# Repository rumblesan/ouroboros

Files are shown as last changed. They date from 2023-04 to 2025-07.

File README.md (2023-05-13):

# Ouroboros

A noisy feedback system

## Description

A pinged filter feeds a PT delay, which feeds a comparator, which feeds some clock dividers, which pings the filter and modulate the rest of the system

## Contact

Drop me an email at guy@rumblesan.com

## License

Creative Commons Licence
This work is licensed under a [Creative Commons Attribution 4.0 International License]("http://creativecommons.org/licenses/by/4.0/")

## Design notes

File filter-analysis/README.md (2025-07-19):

# Filter design docs

For rev 1 and 2 the filter used LM13700 OTAs for the filter.
Rev 3 has been redesigned to use the 2164 gain cell.

This folder has the analysis of the first versions of the filter, but the analysis for the 2164 version still needs to be added.

## Creating

`pdflatex lm13700-filter.tex`

## Contact

Drop me an email at guy@rumblesan.com

## License

Creative Commons Licence
This work is licensed under a [Creative Commons Attribution 4.0 International License]("http://creativecommons.org/licenses/by/4.0/")

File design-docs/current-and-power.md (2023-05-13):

# Current and Power Calculations

## 5V Supply

The 5V rail supplies :

* PT2399 IC
    draws up to ~30ma, less at lower speeds
* CD4020 IC
    Draws up to ~5ua (negligable)
    Output goes straight into a high input impedance buffer so minimal draw there as well.
* ATTiny85
    draws ~2ma (need to properly calculate but it's in this region)
* The 100k Division control potentiometer
    negligable

### Power

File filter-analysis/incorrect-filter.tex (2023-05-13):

\documentclass{article}

\usepackage{amsmath}
\usepackage{graphicx}
\usepackage{enumitem}

\title{Incorrect Filter}
\author{Guy John \\ \texttt{guy@rumblesan.com}}

\begin{document}

\maketitle

\section{Introduction}
Analysis of the original, incorrect design of the Ouroboros filter. Heavily based on the Serge VCFQ, but also with influence from the Mutable Instruments Blades. Much of this is pulled verbatim from the SSM2164 SVF Analysis by Emilie Gillet and then just somewhat modified.

\newpage

\subsection{Notations}

\begin{description}
\item $R_i$ is the value of the resistor through which the input signal is fed to the circuit.
\item $R_f$ is the value of the resistor through which the output signal of the integrator is fed back to the input.
\item $R_s$ is the value of the resistor from the OTA inputs to ground.
\item $C$ is the value of the integrators' capacitors.
\item $R_g$ is the value of the resistor through which the HP and LP outputs are fed back into the input.
\item $R_q$ is the value of the resistor through which the attenuated BP output is fed back into the input.
\item $v_{cv}$ is the cutoff frequency control voltage.
\item $v_q$ is the resonance control voltage.
\item $v_i(s)$ is the input voltage.
\item $v_{hp}(s)$, $v_{bp}(s)$ and $v_{lp}(s)$ are the high-pass, band-pass and low-pass output voltages.
\end{description}

\subsection{OTA Integrator Cell}

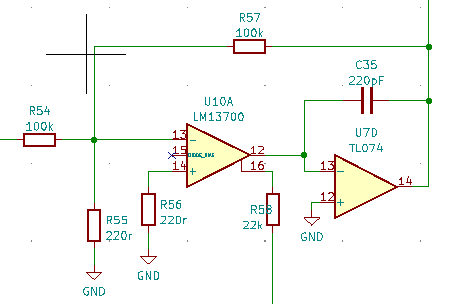
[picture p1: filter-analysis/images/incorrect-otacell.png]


The transfer function of an OTA is:

\begin{equation*}
\begin{split}
  i_o & = g_m(v_+ - v_-) \\
  i_o & = 19.2i_{cv}(v_+ - v_-) \\
\end{split}
\end{equation*}

If $R_f$ is equal to $R_i$
Kirchoff in $v_-$ gives:

\begin{equation*}
\begin{split}
  \frac{1}{R_i}(v_i(s) - v_-(s)) + \frac{1}{R_i}(v_{out}(s) - v_-(s)) & = \frac{1}{R_s}v_-(s) \\
  {R_s}v_i(s) - {R_s}v_-(s) + {R_s}v_{out}(s) - {R_s}v_-(s) & = {R_i}v_-(s) \\
  {R_s}v_i(s) + {R_s}v_{out}(s) - {R_s}v_-(s) - {R_s}v_-(s) & = {R_i}v_-(s) \\
  {R_s}v_i(s) + {R_s}v_{out}(s) - 2{R_s}v_-(s) & = {R_i}v_-(s) \\
  {R_s}v_i(s) + {R_s}v_{out}(s) & = {R_i}v_-(s) + 2{R_s}v_-(s) \\
  {R_s}(v_i(s) + v_{out}(s)) & = v_-(s)({R_i} + 2{R_s}) \\
  \frac{R_s}{{R_i} + 2{R_s}}(v_i(s) + v_{out}(s)) & = v_-(s) \\
\end{split}
\end{equation*}

The current $i_c$ at the output if the OTA is:

\begin{equation*}
\begin{split}
  i_c(s) & = g_m(v_+(s) - v_-(s)) \\
   & = 19.2i_{cv}(0 - \frac{R_s}{{R_i} + 2{R_s}}(v_i(s) + v_{out}(s))) \\
   & = -19.2i_{cv}\frac{R_s}{{R_i} + 2{R_s}}(v_i(s) + v_{out}(s)) \\
\end{split}
\end{equation*}

The voltage out of the OpAmp:

\begin{equation*}
\begin{split}
  v_{out}(s) & = \frac{-i_c(s)}{Cs} \\
  v_{out}(s) & = -(-19.2i_{cv}\frac{R_s}{Cs({R_i} + 2{R_s})}(v_i(s) + v_{out}(s))) \\
  v_{out}(s) & = 19.2i_{cv}\frac{R_s}{Cs({R_i} + 2{R_s})}(v_i(s) + v_{out}(s)) \\
  v_{out}(s)Cs({R_i} + 2{R_s}) & = 19.2i_{cv}R_s(v_i(s) + v_{out}(s)) \\
  v_{out}(s)Cs({R_i} + 2{R_s}) & = v_i(s)19.2i_{cv}R_s + v_{out}(s)19.2i_{cv}R_s \\
  v_{out}(s)Cs({R_i} + 2{R_s}) - v_{out}(s)19.2i_{cv}R_s & = v_i(s)19.2i_{cv}R_s \\
  v_{out}(s)(Cs({R_i} + 2{R_s}) - 19.2\i_{cv}R_s) & = v_i(s)19.2i_{cv}R_s \\
  v_{out}(s) & = v_i(s)\frac{19.2i_{cv}R_s}{Cs({R_i} + 2{R_s}) - 19.2i_{cv}R_s} \\
  v_{out}(s) & = v_i(s)\frac{1}{\frac{({R_i} + 2{R_s})}{R_s}Cs\frac{1}{19.2i_{cv}} - 1} \\
\end{split}
\end{equation*}

So the transfer function is:

\begin{equation}
  \alpha(s) = \frac{1}{\frac{({R_i} + 2{R_s})}{R_s}Cs\frac{1}{19.2i_{cv}} - 1}
\end{equation}

This should work as a single filter stage in itself, with the cutoff frequency being the point at which the ouput is 3dB lower than the input, or $\frac{1}{\sqrt{2}} \approx 0.707$

\begin{equation*}
\begin{split}
  0.707 & = \frac{1}{\frac{({R_i} + 2{R_s})}{R_s}C2\pi{f}\frac{1}{19.2i_{cv}} - 1} \\
  0.707\frac{({R_i} + 2{R_s})}{R_s}C2\pi{f}\frac{1}{19.2i_{cv}} -  0.707 & = 1 \\
  0.707\frac{({R_i} + 2{R_s})}{R_s}C2\pi{f}\frac{1}{19.2i_{cv}} & = 1.707 \\
  \frac{({R_i} + 2{R_s})}{R_s}C2\pi{f}\frac{1}{19.2i_{cv}} & = \frac{19.2i_{cv}1.707}{0.707} \\
  f\frac{({R_i} + 2{R_s})}{R_s}C2\pi & = 19.2i_{cv}2.414 \\
  f & = \frac{19.2i_{cv}2.414}{2\pi\frac{({R_i} + 2{R_s})}{R_s}C} \\
  f & = \frac{19.2i_{cv}1.207}{\pi\frac{({R_i} + 2{R_s})}{R_s}C} \\
  f & = \frac{23.18i_{cv}}{\pi\frac{({R_i} + 2{R_s})}{R_s}C} \\
\end{split}
\end{equation*}

\subsection{Feedback Control}

The gain of the feedback circuit is:

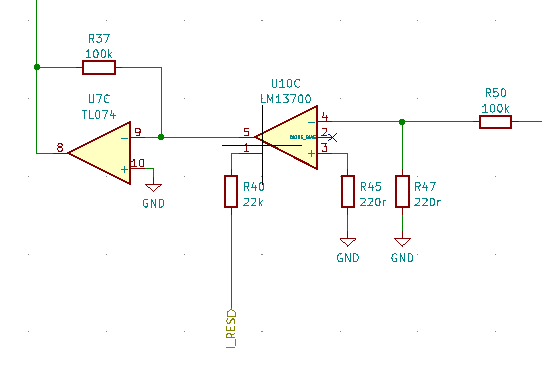
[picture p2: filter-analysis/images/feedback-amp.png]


\begin{equation*}
\begin{split}
  v_- & = v_i\frac{R_s}{R_i + R_s} \\
  i_o & = 19.2i_{res}(0 - v_-) \\
  i_o & = -19.2i_{res}v_i\frac{R_s}{R_i + R_s} \\
  i_o + \frac{v_o}{R_f} & = 0 \\
  i_o & = -\frac{v_o}{R_f} \\
  -i_o{R_f} & = v_o \\
  v_o & = -i_o{R_f} \\
  v_o & = 19.2i_{res}v_i\frac{R_fR_s}{R_i + R_s} \\
  v_o & = 19.2i_{res}v_i\frac{R_fR_s}{R_i + R_s} \\
  \beta & = 19.2i_{res}\frac{R_fR_s}{R_i + R_s} \\
\end{split}
\end{equation*}

\subsection{Filter}

\begin{equation*}
\begin{split}
  \frac{v_i - v_-}{R_i} + \frac{v_{hp} - v_-}{R_f} + \frac{v_{lp} - v_-}{R_f}  + \frac{v_{bp}\beta - v_-}{R_q} & = i_- = 0 \\
  \frac{v_i}{R_i} + \frac{v_{hp}}{R_f} + \frac{v_{lp}}{R_f}  + \frac{v_{bp}\beta}{R_q} & = 0 \\
\end{split}
\end{equation*}

It is important to note that $v_{bp}(s) = v_{hp}(s)\alpha(s)$, and $v_{lp}(s) = v_{hp}(s)\alpha(s^2)$.

\subsubsection{High-pass}

\begin{equation*}
\begin{split}
  \frac{v_{hp}(s)}{R_f} & = - \frac{v_i(s)}{R_i} - \frac{v_{lp}(s)}{R_f} - \frac{v_{bp}(s)\beta}{R_q} \\
  \frac{v_{hp}(s)}{R_f} & = - \frac{v_i(s)}{R_i} - \frac{v_{hp}(s)\alpha(s^2)}{R_f} - \frac{v_{hp}(s)\alpha(s)\beta}{R_q} \\
  H_{hp}(s) & = \frac{v_{hp}(s)}{v_i(s)} \\
  \frac{v_i(s)}{R_i} & = - \frac{v_{hp}(s)}{R_f} - \frac{v_{hp}(s)\alpha(s^2)}{R_f} - \frac{v_{hp}(s)\alpha(s)\beta}{R_q} \\
  \frac{v_i(s)}{R_i} & = - v_{hp}(s)(\frac{1}{R_f} + \frac{\alpha(s^2)}{R_f} + \frac{\alpha(s)\beta}{R_q}) \\
  \frac{1}{R_i} & = - H_{hp}(s)(\frac{1}{R_f} + \frac{\alpha(s^2)}{R_f} + \frac{\alpha(s)\beta}{R_q}) \\
  \frac{-1}{R_i} & = H_{hp}(s)(\frac{1}{R_f} + \frac{\alpha(s^2)}{R_f} + \frac{\alpha(s)\beta}{R_q}) \\
  H_{hp}(s) & = \frac{-1/R_i}{\frac{1}{R_f} + \frac{\alpha(s^2)}{R_f} + \frac{\alpha(s)\beta}{R_q}} \\
  & = \frac{-R_f/R_i}{1 + \frac{R_f\alpha(s)\beta}{R_q} + \alpha(s^2) } \\
\end{split}
\end{equation*}

\subsubsection{Low-Pass}

\begin{equation*}
\begin{split}
  H_{lp}(s) & = \frac{v_{lp}(s)}{v_i(s)} \\
            & = \frac{v_{hp}(s)}{v_i(s)}\alpha^2(s) \\
            & = \frac{-}{\frac{1}{\alpha^2(s)} + \frac{R_f\beta}{R_q\alpha(s)} + 1 } \\
            & = \frac{-R_f/R_i}{\frac{1}{\alpha^2(s)} + \beta\frac{R_f}{R_q}\frac{1}{\alpha(s)} + 1 } \\
            & = \frac{-R_f/R_i}{\frac{1}{(\frac{1}{\frac{{R_i} + 2{R_s}}{R_s}Cs\frac{1}{19.2i_{cv}} - 1})^2} + (19.2i_{res}\frac{R_fR_s}{R_i + R_s})\frac{R_f}{R_q}\frac{1}{(\frac{1}{\frac{{R_i} + 2{R_s}}{R_s}Cs\frac{1}{19.2i_{cv}} - 1})} + 1 } \\
            & = \frac{-R_f/R_i}{(\frac{{R_i} + 2{R_s}}{R_s}Cs\frac{1}{19.2i_{cv}} - 1)^2 + (19.2i_{res}\frac{R_fR_s}{R_i + R_s})\frac{R_f}{R_q}(\frac{{R_i} + 2{R_s}}{R_s}Cs\frac{1}{19.2i_{cv}} - 1) + 1 } \\
            & = \frac{-R_f/R_i}{(\frac{{R_i} + 2{R_s}}{R_s}Cs\frac{1}{19.2i_{cv}})^2 - 2(19.2i_{res}\frac{R_fR_s}{R_i + R_s}) + 1 + (19.2i_{res}\frac{R_fR_s}{R_i + R_s}\frac{R_f}{R_q})(\frac{{R_i} + 2{R_s}}{R_s}Cs\frac{1}{19.2i_{cv}} - 1) + 1 } \\
            & = \frac{-R_f/R_i}{(\frac{{R_i} + 2{R_s}}{R_s}Cs\frac{1}{19.2i_{cv}})^2 - (2 + \frac{R_f}{R_q})(19.2i_{res}\frac{R_fR_s}{R_i + R_s}) + 19.2i_{res}\frac{R_fR_s}{R_i + R_s}\frac{R_f}{R_q}\frac{{R_i} + 2{R_s}}{R_s}Cs\frac{1}{19.2i_{cv}} + 2 } \\
            & = \frac{-R_f/R_i}{(\frac{{R_i} + 2{R_s}}{R_s}Cs\frac{1}{19.2i_{cv}})^2 + 19.2i_{res}\frac{R_fR_s}{R_i + R_s}\frac{R_f}{R_q}(\frac{{R_i} + 2{R_s}}{R_s}Cs\frac{1}{19.2i_{cv}}) - (2 + \frac{R_f}{R_q})(19.2i_{res}\frac{R_fR_s}{R_i + R_s}) + 2 } \\
\end{split}
\end{equation*}

At this point it seems clear that this doesn't fit the standard transfer function for a second order filter....

\end{document}

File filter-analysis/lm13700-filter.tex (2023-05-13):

\documentclass{article}

\usepackage{amsmath}
\usepackage{graphicx}
\usepackage{enumitem}

\title{Ouroboros Filter}
\author{Guy John \\ \texttt{guy@rumblesan.com}}

\begin{document}

\maketitle

\section{Introduction}
Analysis of the Ouroboros filter. Heavily based on the Serge VCFQ, but also with influence from the Mutable Instruments Blades. Much of this is pulled verbatim from the SSM2164 SVF Analysis by Emilie Gillet and then just somewhat modified.

\newpage

\subsection{Notations}

\begin{description}
\item $R_i$ is the value of the resistor through which the input signal is fed to the circuit.
\item $R_g$ is the value of the resistor through which the HP and LP outputs are fed back into the input.
\item $R_q$ is the value of the resistor through which the attenuated BP output is fed back into the input.
\item $R$ and $R_s$ are the values of the resistor at the voltage divider input of the OTAs.
\item $R_f$ is the value of the resistor through which the current at the output of the Q attenuator is converted back
into a voltage.
\item $C$ is the value of the integrators' capacitors.
\item $v_{cv}$ is the cutoff frequency control voltage.
\item $v_q$ is the resonance control voltage.
\item $v_i(s)$ is the input voltage.
\item $v_{hp}(s)$, $v_{bp}(s)$ and $v_{lp}(s)$ are the high-pass, band-pass and low-pass output voltages.
\end{description}

For reference, the standard second-order filter transfer functions are:

\begin{equation*}
\begin{split}
  H_{lp}(s) & = \frac{1}{s^2T^2 + \frac{1}{q}sT + 1} \\
  H_{bp}(s) & = \frac{1}{\frac{q}{sT} + qsT + 1} \\
  H_{hp}(s) & = \frac{1}{\frac{1}{s^2T^2} + \frac{1}{qsT} + 1} \\
\end{split}
\end{equation*}

\subsection{OTA Integrator Cell}

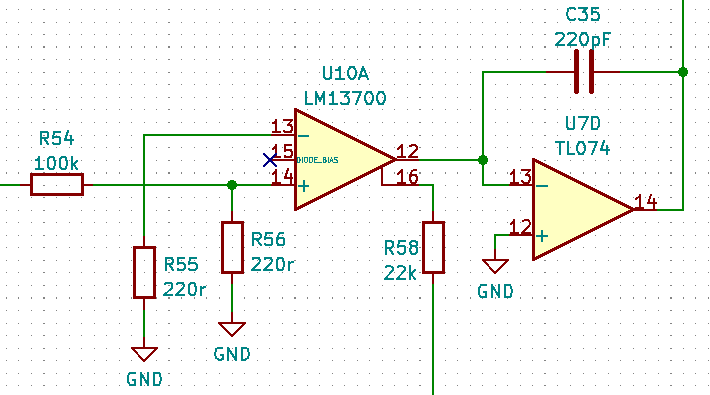
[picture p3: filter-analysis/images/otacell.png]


The transfer function of an OTA is:

\begin{equation*}
\begin{split}
  i_o & = g_m(v_+ - v_-) \\
  i_o & = 19.2i_{cv}(v_+ - v_-) \\
\end{split}
\end{equation*}

If $R_f$ is equal to $R_i$
Kirchoff in $v_+$ gives:

\begin{equation*}
\begin{split}
  \frac{1}{R}(v_i(s) - v_+(s)) & = \frac{1}{R_s}v_+(s) \\
  R_sv_i(s) - R_sv_+(s) & = Rv_+(s) \\
  R_sv_i(s) & = Rv_+(s) + R_sv_+(s) \\
  R_sv_i(s) & = v_+(s)(R + R_s) \\
  v_+(s)(R + R_s) & = R_sv_i(s) \\
  v_+(s) & = \frac{R_s}{R + R_s}v_i(s) \\
\end{split}
\end{equation*}

The current $i_c$ at the output if the OTA is:

\begin{equation*}
\begin{split}
  i_c(s) & = g_m(v_+(s) - v_-(s)) \\
   & = 19.2i_{cv}(\frac{R_s}{R + 2R_s}v_i(s) - 0) \\
   & = 19.2i_{cv}\frac{R_s}{R + 2R_s}v_i(s) \\
\end{split}
\end{equation*}

The voltage out of the OpAmp:

\begin{equation*}
\begin{split}
  v_o(s) & = \frac{-i_c(s)}{Cs} \\
  v_o(s) & = -19.2i_{cv}\frac{R_s}{Cs(R + 2R_s)}v_i(s) \\
\end{split}
\end{equation*}

So the transfer function is:

\begin{equation}
  \alpha(s) = -19.2i_{cv}\frac{R_s}{Cs(R + 2R_s)}
\end{equation}

\subsection{Feedback Control}

The gain of the feedback circuit is:

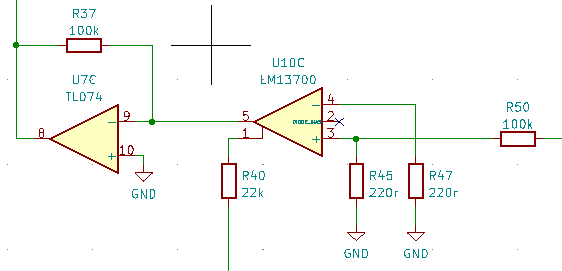
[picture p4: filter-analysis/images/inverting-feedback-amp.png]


\begin{equation*}
\begin{split}
  v_+ & = v_i\frac{R_s}{R + R_s} \\
  i_o & = 19.2i_{q}(v_+ - v_-) \\
  i_o & = 19.2i_{q}(v_+ - 0) \\
  i_o & = 19.2i_{q}v_i\frac{R_s}{R + R_s} \\
  i_o & = R_f(v_- - v_o) \\
  i_o & = -R_fv_o \\
  -R_fv_o & = 19.2i_{q}v_i\frac{R_s}{R + R_s} \\
  -R_fv_o & = 19.2i_{q}v_i\frac{R_s}{R + R_s} \\
  v_o & = -19.2i_{q}v_i\frac{R_fR_s}{R_i + R_s} \\
  \beta & = -19.2i_{q}\frac{R_fR_s}{R_i + R_s} \\
\end{split}
\end{equation*}

\subsection{Filter}

\begin{equation*}
\begin{split}
  \frac{v_i - v_-}{R_i} + \frac{v_{hp} - v_-}{R_g} + \frac{v_{lp} - v_-}{R_g}  + \frac{v_{bp}\beta - v_-}{R_q} & = i_- = 0 \\
  \frac{v_i}{R_i} + \frac{v_{hp}}{R_g} + \frac{v_{lp}}{R_g}  + \frac{v_{bp}\beta}{R_q} & = 0 \\
\end{split}
\end{equation*}

It is important to note that $v_{bp}(s) = v_{hp}(s)\alpha(s)$, and $v_{lp}(s) = v_{hp}(s)\alpha(s^2)$.

\subsubsection{High-pass}

\begin{equation*}
\begin{split}
  \frac{v_{hp}(s)}{R_g} & = - \frac{v_i(s)}{R_i} - \frac{v_{lp}(s)}{R_g} - \frac{v_{bp}(s)\beta}{R_q} \\
  \frac{v_{hp}(s)}{R_g} & = - \frac{v_i(s)}{R_i} - \frac{v_{hp}(s)\alpha(s^2)}{R_g} - \frac{v_{hp}(s)\alpha(s)\beta}{R_q} \\
  \frac{v_i(s)}{R_i} & = - \frac{v_{hp}(s)}{R_g} - \frac{v_{hp}(s)\alpha(s^2)}{R_g} - \frac{v_{hp}(s)\alpha(s)\beta}{R_q} \\
  H_{hp}(s) & = \frac{v_{hp}(s)}{v_i(s)} \\
  \frac{v_i(s)}{R_i} & = - v_{hp}(s)(\frac{1}{R_g} + \frac{\alpha(s^2)}{R_g} + \frac{\alpha(s)\beta}{R_q}) \\
  \frac{1}{R_i} & = - H_{hp}(s)(\frac{1}{R_g} + \frac{\alpha(s^2)}{R_g} + \frac{\alpha(s)\beta}{R_q}) \\
  \frac{-1}{R_i} & = H_{hp}(s)(\frac{1}{R_g} + \frac{\alpha(s^2)}{R_g} + \frac{\alpha(s)\beta}{R_q}) \\
  H_{hp}(s) & = \frac{-1/R_i}{\frac{1}{R_g} + \frac{\alpha(s^2)}{R_g} + \frac{\alpha(s)\beta}{R_q}} \\
  & = \frac{-R_g/R_i}{1 + \frac{R_g\alpha(s)\beta}{R_q} + \alpha(s^2) } \\
\end{split}
\end{equation*}

\subsubsection{Low-Pass}

\begin{equation*}
\begin{split}
  H_{lp}(s) & = \frac{v_{lp}(s)}{v_i(s)} \\
            & = \frac{v_{hp}(s)}{v_i(s)}\alpha^2(s) \\
            & = \frac{-R_g/R_i}{\frac{1}{\alpha^2(s)} + \frac{R_g\beta}{R_q\alpha(s)} + 1 } \\
            & = \frac{-R_g/R_i}{\frac{1}{\alpha^2(s)} + \beta\frac{R_g}{R_q}\frac{1}{\alpha(s)} + 1 } \\
            & = \frac{-R_g/R_i}{\frac{1}{(-19.2i_{cv}\frac{R_s}{Cs(R + 2R_s)})^2} + (-19.2i_{q}\frac{R_fR_s}{R_i + R_s})\frac{R_g}{R_q}\frac{1}{-19.2i_{cv}\frac{R_s}{Cs(R + 2R_s)}} + 1 } \\
            & = \frac{-R_g/R_i}{\frac{1}{(19.2i_{cv}\frac{R_s}{Cs(R + 2R_s)})^2} + 19.2i_{q}\frac{R_fR_s}{R_i + R_s}\frac{R_g}{R_q}\frac{1}{19.2i_{cv}\frac{R_s}{Cs(R + 2R_s)}} + 1 } \\
            & = \frac{-R_g/R_i}{\frac{1}{\frac{1}{s^2}(19.2i_{cv}\frac{R_s}{C(R + 2R_s)})^2} + 19.2i_{q}\frac{R_fR_s}{R_i + R_s}\frac{R_g}{R_q}\frac{1}{19.2i_{cv}\frac{1}{s}\frac{R_s}{C(R + 2R_s)}} + 1 } \\
            & = \frac{-R_g/R_i}{\frac{s^2}{(19.2i_{cv}\frac{R_s}{C(R + 2R_s)})^2} + 19.2i_{q}\frac{R_fR_s}{R_i + R_s}\frac{R_g}{R_q}\frac{s}{19.2i_{cv}\frac{R_s}{C(R + 2R_s)}} + 1 } \\
\end{split}
\end{equation*}

One simplification worth making is to say that $R_q = R_g$.

By comparing with the standard form of a second order filter transfer function we can work out the following.

\begin{description}
  \item Pass-band gain, $-\frac{R_g}{R_i}$
  \item Cutoff frequency, $19.2i_{cv}\frac{R_s}{C2\pi(R + 2R_s)}$
  \item Quality factor, $\frac{1}{19.2i_{q}\frac{R_fR_s}{R_i + R_s}}$
\end{description}

\subsection{Calculating cutoff frequencies}

Given the calculation for frequency, and picking some standard values we can calculate cutoff for different $i_{cv}$ values.

\begin{description}
  \item $R$ is 100k
  \item $R_s$ is 220r
  \item $C$ is 220pF
\end{description}

\begin{equation}
  f = 19.2i_{cv}\frac{220}{220 * 10^{-12} * 2\pi(100000 + 2(220))}
\end{equation}

\begin{description}
  \item for $i_{cv}$ of 0.5ma $f = 15212Hz$
  \item for $i_{cv}$ of 0.3ma $f = 9127Hz$
  \item for $i_{cv}$ of 0.1ma $f = 3042Hz$
  \item for $i_{cv}$ of 0.05ma $f = 1521Hz$
  \item for $i_{cv}$ of 0.01ma $f = 304Hz$
\end{description}

\subsection{Calculating resonance}

A quality factor of $1/2$ gives no resonance, whilst the resonance (and likelihood of self oscillating) increases as Q goes to infinity.

\begin{description}
  \item $R_f$ is 100k
  \item $R_i$ is 100k
  \item $R_s$ is 220r
  \item $C$ is 220pF
\end{description}

\begin{equation}
  q = \frac{1}{19.2i_{q}\frac{100000 * 220}{100000 + 220}}
\end{equation}

\begin{description}
  \item for $i_{q}$ of 0.5ma $q = 0.47$
  \item for $i_{q}$ of 0.3ma $q = 0.79$
  \item for $i_{q}$ of 0.1ma $q = 2.37$
  \item for $i_{q}$ of 0.05ma $q = 4.75$
  \item for $i_{q}$ of 0.01ma $q = 23.7$
\end{description}

\end{document}

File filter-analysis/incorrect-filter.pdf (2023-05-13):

# Incorrect Filter

Guy John
guy@rumblesan.com

May 13, 2023

## 1 Introduction

Analysis of the original, incorrect design of the Ouroboros filter. Heavily based on the Serge VCFQ, but also with influence from the Mutable Instruments Blades. Much of this is pulled verbatim from the SSM2164 SVF Analysis by Emilie Gillet and then just somewhat modified.

1

### 1.1 Notations

Ri

is the value of the resistor through which the input signal is fed to the circuit.

Rf is the value of the resistor through which the output signal of the integrator is fed back to the input.

Rs is the value of the resistor from the OTA inputs to ground.

C is the value of the integrators’ capacitors.

Rg is the value of the resistor through which the HP and LP outputs are fed back into the input.

Rq is the value of the resistor through which the attenuated BP output is fed back into the input.

vcv is the cutoff frequency control voltage.

vq is the resonance control voltage.

vi(s) is the input voltage.

vhp(s), vbp(s) and vlp(s) are the high-pass, band-pass and low-pass output voltages.

### 1.2 OTA Integrator Cell


The transfer function of an OTA is:

2

io = gm(v+ − v−)
io = 19.2icv(v+ − v−)

If Rf is equal to Ri Kirchoff in v− gives:

1
Ri

(vi(s) − v−(s)) + 1
Ri

(vout(s) − v−(s)) = 1
Rs

v−(s)

Rsvi(s) − Rsv−(s) + Rsvout(s) − Rsv−(s) = Riv−(s) Rsvi(s) + Rsvout(s) − Rsv−(s) − Rsv−(s) = Riv−(s) Rsvi(s) + Rsvout(s) − 2Rsv−(s) = Riv−(s) Rsvi(s) + Rsvout(s) = Riv−(s) + 2Rsv−(s) Rs(vi(s) + vout(s)) = v−(s)(Ri + 2Rs) Rs
Ri + 2Rs

(vi(s) + vout(s)) = v−(s)

The current ic at the output if the OTA is:

ic(s) = gm(v+(s) − v−(s))

= 19.2icv(0 −

Rs
Ri + 2Rs

(vi(s) + vout(s)))

= −19.2icv

Rs
Ri + 2Rs

(vi(s) + vout(s))

The voltage out of the OpAmp:

vout(s) = −ic(s)
Cs

vout(s) = −(−19.2icv

Rs
Cs(Ri + 2Rs)

(vi(s) + vout(s)))

vout(s) = 19.2icv

Rs
Cs(Ri + 2Rs)

(vi(s) + vout(s))

vout(s)Cs(Ri + 2Rs) = 19.2icvRs(vi(s) + vout(s)) vout(s)Cs(Ri + 2Rs) = vi(s)19.2icvRs + vout(s)19.2icvRs vout(s)Cs(Ri + 2Rs) − vout(s)19.2icvRs = vi(s)19.2icvRs vout(s)(Cs(Ri + 2Rs) − 19.2ıcvRs) = vi(s)19.2icvRs

vout(s) = vi(s)

19.2icvRs
Cs(Ri + 2Rs) − 19.2icvRs

vout(s) = vi(s)

1

(Ri+2Rs)
Rs

Cs 1 19.2icv
− 1

3

So the transfer function is:

α(s) = | 1

(Ri+2Rs)
Rs

Cs 1
19.2icv

− 1

(1)

This should work as a single filter stage in itself, with the cutoff frequency being the point at which the ouput is 3dB lower than the input, or √

1
2

≈ 0.707

0.707 =

1

(Ri+2Rs)
Rs

C2πf 1
19.2icv

− 1

0.707

(Ri + 2Rs)
Rs

C2πf 1
19.2icv

− 0.707 = 1

0.707

(Ri + 2Rs)
Rs

C2πf 1
19.2icv

= 1.707

(Ri + 2Rs)
Rs

C2πf 1
19.2icv

=

19.2icv1.707
0.707

f

(Ri + 2Rs)
Rs

C2π = 19.2icv2.414

f =

19.2icv2.414
2π

(Ri+2Rs)
Rs

C

f =

19.2icv1.207
π

(Ri+2Rs)
Rs

C

f =

23.18icv
π

(Ri+2Rs)
Rs

C

### 1.3 Feedback Control

The gain of the feedback circuit is:

4


v− = vi

Rs
Ri + Rs
io = 19.2ires(0 − v−)

io = −19.2iresvi

Rs
Ri + Rs

io +

vo
Rf

= 0

io = −

vo
Rf
−ioRf = vo
vo = −ioRf

vo = 19.2iresvi

RfRs
Ri + Rs

vo = 19.2iresvi

RfRs
Ri + Rs

β = 19.2ires

RfRs
Ri + Rs

5

### 1.4 Filter

vi − v−
Ri

+

vhp − v−
Rf

+

vlp − v−
Rf

+

vbpβ − v−
Rq

= i− = 0

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
vbpβ
Rq

= 0

It is important to note that vbp(s) = vhp(s)α(s), and vlp(s) = vhp(s)α(s

2
).

### 1.4.1 High-pass

vhp(s)
Rf

= −

vi(s)
Ri

−

vlp(s)
Rf

−

vbp(s)β
Rq
vhp(s)
Rf

= −

vi(s)
Ri

−

vhp(s)α(s

2
)
Rf

−

vhp(s)α(s)β
Rq
Hhp(s) = vhp(s)
vi(s)
vi(s)
Ri

= −

vhp(s)
Rf

−

vhp(s)α(s

2
)
Rf

−

vhp(s)α(s)β
Rq
vi(s)
Ri

= −vhp(s)( 1
Rf

+

α(s

2
)
Rf

+

α(s)β
Rq

)

1
Ri

= −Hhp(s)( 1
Rf

+

α(s

2
)
Rf

+

α(s)β
Rq

)

−1
Ri

= Hhp(s)( 1
Rf

+

α(s

2
)
Rf

+

α(s)β
Rq

)

Hhp(s) = | −1/Ri

1
Rf

+

| α(s 2) Rf +
α(s)β
Rq
= | −Rf /Ri 1 + Rf α(s)β Rq + α(s

2)

6

### 1.4.2 Low-Pass

Hlp(s) = vlp(s)
vi(s)

=

vhp(s)
vi(s)

α

2
(s)

=

−

1
α²(s) +

Rf β
Rqα(s) + 1

=

−Rf /Ri

1
α²(s) + β

Rf
Rq

1
α(s) + 1

=

−Rf /Ri

1
(

1
Ri+2Rs
Rs

Cs 1
19.2icv

−1

)

2 + (19.2ires

Rf Rs
Ri+Rs

)

Rf
Rq

1
(

1
Ri+2Rs
Rs

Cs 1
19.2icv

−1

)

+ 1

=

−Rf /Ri
(

Ri+2Rs
Rs

Cs 1
19.2icv

− 1)² + (19.2ires

Rf Rs
Ri+Rs

)

Rf
Rq

(

Ri+2Rs
Rs

Cs 1
19.2icv

− 1) + 1

=

−Rf /Ri
(

Ri+2Rs
Rs

Cs 1
19.2icv

)

2 − 2(19.2ires

Rf Rs
Ri+Rs

) + 1 + (19.2ires

Rf Rs
Ri+Rs

Rf
Rq

)( Ri+2Rs
Rs

Cs 1
19.2icv

− 1) + 1

=

−Rf /Ri
(

Ri+2Rs
Rs

Cs 1
19.2icv

)

2 − (2 + Rf
Rq

)(19.2ires

Rf Rs
Ri+Rs

) + 19.2ires

Rf Rs
Ri+Rs

Rf
Rq

Ri+2Rs
Rs

Cs 1
19.2icv

+ 2

=

−Rf /Ri
(

Ri+2Rs
Rs

Cs 1
19.2icv

)

2 + 19.2ires

Rf Rs
Ri+Rs

Rf
Rq

(

Ri+2Rs
Rs

Cs 1
19.2icv

) − (2 + Rf
Rq

)(19.2ires

Rf Rs
Ri+Rs

) + 2

At this point it seems clear that this doesn’t fit the standard transfer function for a second order filter....

7

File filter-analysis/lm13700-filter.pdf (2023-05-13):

# Ouroboros Filter

Guy John
guy@rumblesan.com

May 13, 2023

## 1 Introduction

Analysis of the Ouroboros filter. Heavily based on the Serge VCFQ, but also with influence from the Mutable Instruments Blades. Much of this is pulled ver-batim from the SSM2164 SVF Analysis by Emilie Gillet and then just somewhat modified.

1

### 1.1 Notations

Ri

is the value of the resistor through which the input signal is fed to the circuit.

Rg is the value of the resistor through which the HP and LP outputs are fed back into the input.

Rq is the value of the resistor through which the attenuated BP output is fed back into the input.

R and Rs are the values of the resistor at the voltage divider input of the OTAs.

Rf is the value of the resistor through which the current at the output of the Q attenuator is converted back into a voltage.

C is the value of the integrators’ capacitors.

vcv is the cutoff frequency control voltage.

vq is the resonance control voltage.

vi(s) is the input voltage.

vhp(s), vbp(s) and vlp(s) are the high-pass, band-pass and low-pass output voltages.

For reference, the standard second-order filter transfer functions are:

Hlp(s) = | 1
s
| 2T² +
| 1 q
sT + 1
Hbp(s) = | 1

q
| sT + qsT + 1
Hhp(s) = | 1

1
s
| 2T ² +

1
| qsT + 1

2

### 1.2 OTA Integrator Cell

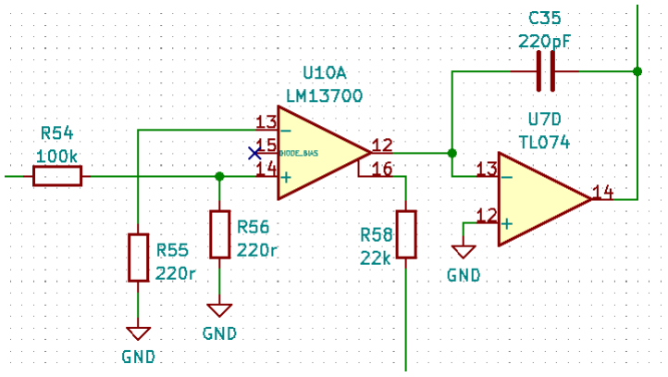
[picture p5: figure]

The transfer function of an OTA is:

io = gm(v+ − v−)
io = 19.2icv(v+ − v−)

If Rf is equal to Ri Kirchoff in v+ gives:

1
R

(vi(s) − v+(s)) = 1
Rs

v+(s)

Rsvi(s) − Rsv+(s) = Rv+(s) Rsvi(s) = Rv+(s) + Rsv+(s) Rsvi(s) = v+(s)(R + Rs)
v+(s)(R + Rs) = Rsvi(s)
v+(s) = Rs R + Rs
vi(s)

The current ic at the output if the OTA is:

ic(s) = gm(v+(s) − v−(s))

= 19.2icv(

Rs
R + 2Rs

vi(s) − 0)

= 19.2icv

Rs
R + 2Rs
| vi(s)

The voltage out of the OpAmp:

3

vo(s) = −ic(s)
Cs

vo(s) = −19.2icv

Rs
Cs(R + 2Rs)

vi(s)

So the transfer function is:

α(s) = −19.2icv

Rs
Cs(R + 2Rs)

(1)

### 1.3 Feedback Control

The gain of the feedback circuit is:


v+ = vi

Rs
R + Rs
io = 19.2iq(v+ − v−)
io = 19.2iq(v+ − 0)

io = 19.2iqvi

Rs
R + Rs
io = Rf (v− − vo)
io = −Rf vo

−Rf vo = 19.2iqvi

Rs
R + Rs

−Rf vo = 19.2iqvi

Rs
R + Rs

vo = −19.2iqvi

RfRs
Ri + Rs

β = −19.2iq

RfRs
Ri + Rs

4

### 1.4 Filter

vi − v−
Ri

+

vhp − v−
Rg

+

vlp − v−
Rg

+

vbpβ − v−
Rq

= i− = 0

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
vbpβ
Rq

= 0

It is important to note that vbp(s) = vhp(s)α(s), and vlp(s) = vhp(s)α(s

2
).

### 1.4.1 High-pass

vhp(s)
Rg

= −

vi(s)
Ri

−

vlp(s)
Rg

−

vbp(s)β
Rq
vhp(s)
Rg

= −

vi(s)
Ri

−

vhp(s)α(s

2
)
Rg

−

vhp(s)α(s)β
Rq
vi(s)
Ri

= −

vhp(s)
Rg

−

vhp(s)α(s

2
)
Rg

−

vhp(s)α(s)β
Rq
Hhp(s) = vhp(s)
vi(s)
vi(s)
Ri

= −vhp(s)( 1
Rg

+

α(s

2
)
Rg

+

α(s)β
Rq

)

1
Ri

= −Hhp(s)( 1
Rg

+

α(s

2
)
Rg

+

α(s)β
Rq

)

−1
Ri

= Hhp(s)( 1
Rg

+

α(s

2
)
Rg

+

α(s)β
Rq

)

Hhp(s) = | −1/Ri

1
Rg

+

| α(s 2) Rg +
α(s)β
Rq
= | −Rg/Ri 1 + Rgα(s)β Rq + α(s

2)

5

### 1.4.2 Low-Pass

Hlp(s) = vlp(s)
vi(s)

=

vhp(s)
vi(s)

α

2
(s)

=

−Rg/Ri

1
α²(s) +

Rgβ
Rqα(s) + 1

=

−Rg/Ri

1
α²(s) + β

Rg
Rq

1
α(s) + 1

=

−Rg/Ri

1
(−19.2icv

Rs
Cs(R+2Rs)

)

2 + (−19.2iq

Rf Rs
Ri+Rs

)

Rg
Rq

1
−19.2icv

Rs
Cs(R+2Rs)

+ 1

=

−Rg/Ri

1
(19.2icv

Rs
Cs(R+2Rs)

)

2 + 19.2iq

Rf Rs
Ri+Rs

Rg
Rq

1
19.2icv

Rs
Cs(R+2Rs)

+ 1

=

−Rg/Ri

1
1
s2

(19.2icv

Rs
C(R+2Rs)

)

2 + 19.2iq

Rf Rs
Ri+Rs

Rg
Rq

1
19.2icv

1
s

Rs
C(R+2Rs)

+ 1

=

−Rg/Ri

s

2
(19.2icv

Rs
C(R+2Rs)

)

2 + 19.2iq

Rf Rs
Ri+Rs

Rg
Rq

s
19.2icv

Rs
C(R+2Rs)

+ 1

One simplification worth making is to say that Rq = Rg.
By comparing with the standard form of a second order filter transfer function we can work out the following.

Pass-band gain, −

Rg
Ri

Cutoff frequency, 19.2icv

Rs
C2π(R+2Rs)
Quality factor, 1
19.2iq
| Rf Rs Ri+Rs

### 1.5 Calculating cutoff frequencies

Given the calculation for frequency, and picking some standard values we can calculate cutoff for different icv values.

R is 100k

Rs is 220r

C is 220pF

f = 19.2icv

220
220 ∗ 10⁻¹² ∗ 2π(100000 + 2(220)) | (2)

6

for icv of 0.5ma f = 15212Hz

for icv of 0.3ma f = 9127Hz

for icv of 0.1ma f = 3042Hz

for icv of 0.05ma f = 1521Hz

for icv of 0.01ma f = 304Hz

### 1.6 Calculating resonance

A quality factor of 1/2 gives no resonance, whilst the resonance (and likelihood of self oscillating) increases as Q goes to infinity.

Rf is 100k

Ri

is 100k

Rs is 220r

C is 220pF

q =

1
19.2iq

100000∗220
100000+220

(3)

for iq of 0.5ma q = 0.47

for iq of 0.3ma q = 0.79

for iq of 0.1ma q = 2.37

for iq of 0.05ma q = 4.75

for iq of 0.01ma q = 23.7

7

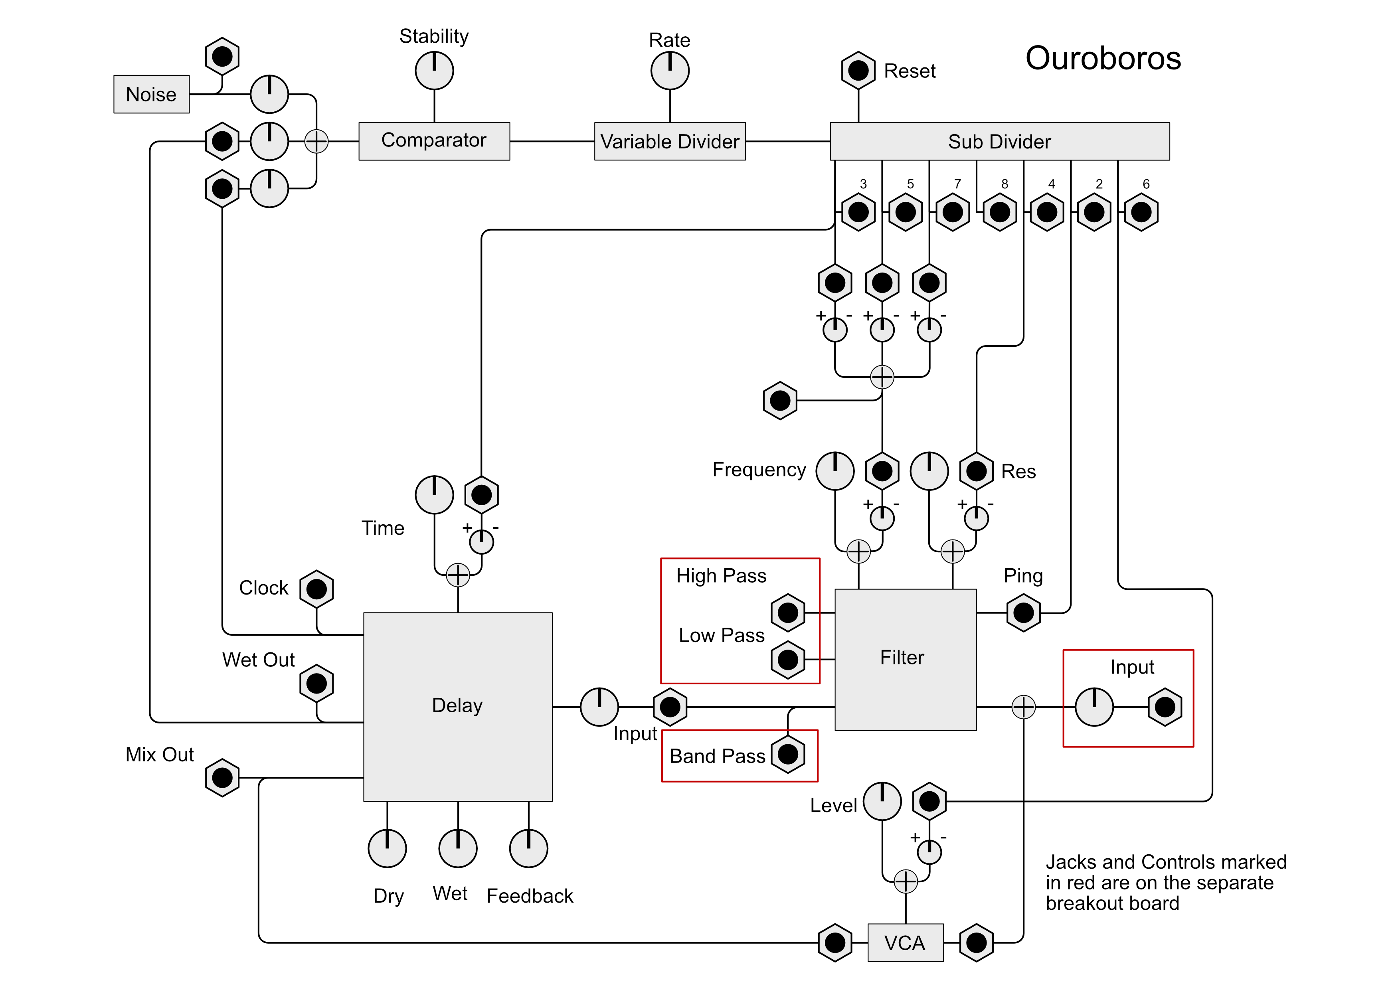
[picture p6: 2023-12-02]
docs/diagram.png

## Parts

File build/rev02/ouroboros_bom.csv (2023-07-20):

Component | Description | Part | References | Value | Footprint | PartNumber | Quantity Per PCB | Spec | Tolerance | Voltage | Sim.Device | Sim.Pins | Name | mpn | Power
1 | Unpolarized capacitor | C | C3 C6 C7 C10 C13 C14 C16 C24 C25 C31 C39 C40 C43 C52 C57 C64 | 22pF | C_Rect_L7.0mm_W2.5mm_P5.00mm |  | 16 | ceramic C0G | 5%
2 | Unpolarized capacitor | C | C33 C46 C58 | 220pF | C_Rect_L7.0mm_W2.5mm_P5.00mm |  | 3 | ceramic C0G | 5%
3 | Unpolarized capacitor | C | C48 C49 | 220pF | C_Rect_L7.0mm_W2.5mm_P5.00mm |  | 2 | film polypropylene | 5%
4 | Unpolarized capacitor | C | C28 C29 | 560pF | C_Rect_L7.0mm_W3.5mm_P5.00mm |  | 2 | ceramic C0G | 5%
5 | Unpolarized capacitor | C | C34 C60 C66 | 10nF | C_Rect_L7.0mm_W2.5mm_P5.00mm |  | 3 | ceramic C0G | 5%
6 | Unpolarized capacitor | C | C1 C2 C4 C5 C8 C9 C11 C12 C15 C17 C23 C35 C37 C41 C42 C44 C45 C47 C50 C51 C53 C54 C55 C56 C59 C61 C65 | 100nF | C_Rect_L7.0mm_W2.5mm_P5.00mm |  | 27 | ceramic X7R | 5%
7 | Unpolarized capacitor | C | C19 C20 C26 C30 | 100nF | C_Rect_L7.0mm_W3.5mm_P5.00mm |  | 4 | ceramic C0G | 5%
8 | Unpolarized capacitor | C | C18 | 470nF | C_Rect_L7.0mm_W3.5mm_P5.00mm |  | 1 | ceramic X7R | 5%
9 | Polarized capacitor | C_Polarized | C21 C22 C32 C62 C63 | 10uF | CP_Radial_D5.0mm_L11.0mm_P2.00mm_Horizontal |  | 5 | electrolytic | 20% | 50v
10 | Polarized capacitor | C_Polarized | C27 | 47uF | CP_Radial_D5.0mm_L11.0mm_P2.00mm_Horizontal |  | 1 | electrolytic | 20% | 50v
11 | Unpolarized capacitor | C | C36 C38 | 4n7F | C_Rect_L7.0mm_W3.5mm_P5.00mm |  | 2 | ceramic C0G | 5%
12 | Diode | D | D1 D2 D3 D4 D6 D8 D9 D10 D11 D12 D13 D14 D17 D18 D19 D22 | 1N4148 | D_DO-35_SOD27_P7.62mm_Horizontal |  | 16 |  |  |  | D | 1=K 2=A
13 | 30V 1A Schottky Barrier Rectifier Diode, DO-41 | 1N5818 | D5 D7 D20 D21 | 1N5818 | D_DO-41_SOD81_P10.16mm_Horizontal |  | 4
14 | Zener diode | D_Zener | D15 D16 | 6v8 | D_DO-35_SOD27_P7.62mm_Horizontal |  | 2 | 6.8v zener
15 | Generic connector, single row, 01x03, script generated | Conn_01x03_Pin | J10 J37 | Conn_01x03_Male | PinHeader_1x03_P2.54mm_Vertical |  | 2 |  |  |  |  |  | Zener Limiter
16 | Generic connector, single row, 01x04, script generated | Conn_01x04_Socket | J42 J44 J45 J46 | Conn_01x04_Female | PinSocket_1x04_P2.54mm_Vertical |  | 4
17 | Generic connector, single row, 01x04, script generated | Conn_01x04_Pin | J29 J30 J31 J33 | Conn_01x04_Male | PinHeader_1x04_P2.54mm_Vertical |  | 4
18 | Generic connector, single row, 01x06, script generated | Conn_01x06_Socket | J43 J47 | Conn_01x06_Female | PinSocket_1x06_P2.54mm_Vertical |  | 2
19 | Generic connector, single row, 01x06, script generated | Conn_01x06_Pin | J28 J32 | Conn_01x06_Male | PinHeader_1x06_P2.54mm_Vertical |  | 2
20 | Generic connector, single row, 01x08, script generated | Conn_01x08_Socket | J40 J41 | Conn_01x08_Female | PinSocket_1x08_P2.54mm_Vertical |  | 2
21 | Generic connector, single row, 01x08, script generated | Conn_01x08_Pin | J34 J35 | Conn_01x08_Male | PinHeader_1x08_P2.54mm_Vertical |  | 2
22 | Generic connector, double row, 02x04, odd/even pin numbering scheme (row 1 odd numbers, row 2 even numbers), script generated (kicad-library-utils/schlib/autogen/connector/) | Conn_02x04_Odd_Even | J38 | Conn_02x04_Odd_Even | PinHeader_2x04_P2.54mm_Vertical |  | 1
23 | Eurorack vertical jack, 2 Poles (Mono / TS), Switched T Pole (Normalling) | Eurorack_Mono_Jack | J1 J2 J3 J4 J5 J6 J7 J8 J9 J11 J12 J13 J14 J15 J16 J17 J18 J19 J20 J21 J22 J23 J24 J25 J26 J27 | Eurorack Mono Jack | Jack_3.5mm_QingPu_WQP-PJ398SM_Vertical |  | 26 |  |  |  |  |  | Noise Out Delay Wet Mix In Delay Wet Out Audio Out Delay Clock Mix In Delay Clock Out VCA Input VCA Level CV Delay Time CV VCA Output Delay Input Filter Resonance CV Filter Frequency CV CV Mix 3 CV Mix Out /7 /5 /3 Divider Reset /8 /6 /4 /2 Filter Ping | WQP-WQP518MA
24 |  | Eurorack Power Small | J36 | Eurorack Power Small | Eurorack_PowerHeader_2x05_P2.54mm_Shrouded |  | 1
25 | Generic connector, double row, 02x03, odd/even pin numbering scheme (row 1 odd numbers, row 2 even numbers), script generated (kicad-library-utils/schlib/autogen/connector/) | Conn_02x03_Odd_Even | J39 | SPI | PinHeader_2x03_P2.54mm_Vertical |  | 1
26 | 0.2A Ic, 40V Vce, Small Signal NPN Transistor, TO-92 | 2N3904 | Q3 Q4 Q5 Q6 Q8 Q10 | 2N3904 | TO-92_Inline_Wide |  | 6
27 | -0.2A Ic, -40V Vce, Small Signal PNP Transistor, TO-92 | 2N3906 | Q7 Q9 Q11 | 2N3906 | TO-92_Inline_Wide |  | 3
28 | 0.1A Ic, 45V Vce, Small Signal NPN Transistor, TO-92 | BC547 | Q1 | BC547 | TO-92_Inline_Wide |  | 1
29 | 0.2A Ic, 40V Vce, Small Signal NPN Transistor, TO-92 | 2N3904 | Q2 | BC549C | TO-92_Inline_Wide |  | 1
30 | Resistor | R | R4 | 22r | R_Axial_DIN0207_L6.3mm_D2.5mm_P10.16mm_Horizontal |  | 1 | metal film | 1% |  |  |  |  |  | 0.5W
31 | Resistor | R | R90 R91 R95 R96 R98 R108 R113 R117 | 220r | R_Axial_DIN0207_L6.3mm_D2.5mm_P10.16mm_Horizontal |  | 8 | metal film | 1% |  |  |  |  |  | 0.5W
32 | Resistor | R | R86 R87 R103 | 330r | R_Axial_DIN0207_L6.3mm_D2.5mm_P10.16mm_Horizontal |  | 3 | metal film | 1% |  |  |  |  |  | 0.5W
33 | Resistor | R | R2 R8 R13 R22 R27 R33 R35 R37 R42 R43 R46 | 330r | R_Axial_DIN0207_L6.3mm_D2.5mm_P10.16mm_Horizontal |  | 11 | metal film | 1% |  |  |  |  |  | 0.5W
34 | Resistor | R | R5 R39 R41 R44 | 330r | R_Axial_DIN0207_L6.3mm_D2.5mm_P2.54mm_Vertical |  | 4 | metal film | 1% |  |  |  |  |  | 0.5W
35 | Resistor | R | R55 R115 | 470r | R_Axial_DIN0207_L6.3mm_D2.5mm_P10.16mm_Horizontal |  | 2 | metal film | 1% |  |  |  |  |  | 0.5W
36 | Resistor | R | R45 R75 R81 R110 | 1k | R_Axial_DIN0207_L6.3mm_D2.5mm_P10.16mm_Horizontal |  | 4 | metal film | 1% |  |  |  |  |  | 0.5W
37 | Resistor | R | R21 R69 R84 R116 | 2k2 | R_Axial_DIN0207_L6.3mm_D2.5mm_P10.16mm_Horizontal |  | 4 | metal film | 1% |  |  |  |  |  | 0.5W
38 | Resistor | R | R12 R16 R23 R59 R60 R64 R67 R68 R70 R71 R80 R82 R97 | 10k | R_Axial_DIN0207_L6.3mm_D2.5mm_P10.16mm_Horizontal |  | 13 | metal film | 1% |  |  |  |  |  | 0.5W
39 | Resistor | R | R79 R100 R107 R111 R114 R125 R126 | 20k | R_Axial_DIN0207_L6.3mm_D2.5mm_P10.16mm_Horizontal |  | 7 | metal film | 1% |  |  |  |  |  | 0.5W
40 | Resistor | R | R50 R94 | 33k | R_Axial_DIN0207_L6.3mm_D2.5mm_P10.16mm_Horizontal |  | 2 | metal film | 1% |  |  |  |  |  | 0.5W
41 | Resistor | R | R9 R11 R40 R47 R56 R58 R61 | 47k | R_Axial_DIN0207_L6.3mm_D2.5mm_P10.16mm_Horizontal |  | 7 | metal film | 1% |  |  |  |  |  | 0.5W
42 | Resistor | R | R118 | 51k | R_Axial_DIN0207_L6.3mm_D2.5mm_P10.16mm_Horizontal |  | 1 | metal film | 1% |  |  |  |  |  | 0.5W
43 | Resistor | R | R1 R6 R7 R10 R14 R15 R18 R20 R24 R25 R28 R29 R30 R31 R32 R34 R36 R38 R48 R49 R51 R52 R53 R62 R63 R65 R73 R74 R76 R78 R83 R88 R89 R92 R93 R99 R101 R102 R104 R105 R106 R109 R119 R120 R122 R128 R129 | 100k | R_Axial_DIN0207_L6.3mm_D2.5mm_P10.16mm_Horizontal |  | 47 | metal film | 1% |  |  |  |  |  | 0.5W
44 | Resistor | R | R26 R57 | 120k | R_Axial_DIN0207_L6.3mm_D2.5mm_P10.16mm_Horizontal |  | 2 | metal film | 1% |  |  |  |  |  | 0.5W
45 | Resistor | R | R123 R124 R127 | 180k | R_Axial_DIN0207_L6.3mm_D2.5mm_P10.16mm_Horizontal |  | 3 | metal film | 1% |  |  |  |  |  | 0.5W
46 | Resistor | R | R17 R77 R85 R112 | 220k | R_Axial_DIN0207_L6.3mm_D2.5mm_P10.16mm_Horizontal |  | 4 | metal film | 1% |  |  |  |  |  | 0.5W
47 | Resistor | R | R19 R72 R121 | 330k | R_Axial_DIN0207_L6.3mm_D2.5mm_P10.16mm_Horizontal |  | 3 | metal film | 1% |  |  |  |  |  | 0.5W
48 | Resistor | R | R3 R54 R66 | 560k | R_Axial_DIN0207_L6.3mm_D2.5mm_P10.16mm_Horizontal |  | 3 | metal film | 1% |  |  |  |  |  | 0.5W
49 | Resistor | R | R130 | 1M5 | R_Axial_DIN0207_L6.3mm_D2.5mm_P10.16mm_Horizontal |  | 1 | metal film | 1% |  |  |  |  |  | 0.5W
50 | Trim-potentiometer | R_Potentiometer_Trim | RV22 | 100r | Potentiometer_THT_Bourns_3306P_Vertical |  | 1 | single turn
51 | Potentiometer | R_Potentiometer | RV2 RV3 RV4 RV5 RV6 RV7 RV8 RV9 RV10 RV11 RV12 RV13 RV14 RV15 RV16 RV17 RV18 RV19 RV20 RV21 | 100kB | Potentiometer_Alpha_RD901F-40-00D_Single_Vertical |  | 20 |  |  |  |  |  | Delay Wet Stability Feedback Level Delay Feedback Stability Noise Level Delay Clock Stability Feedback Level Delay Wet Level Delay Dry Level Fixed Stability Voltage VCA Level CV Attenuverter Delay Input Level Division CV Mix Level 3 Filter Resonance CV Attenuverter Filter Frequency CV Attenuverter
52 | Trim-potentiometer | R_Potentiometer_Trim | RV1 | 200kB | Potentiometer_THT_Bourns_3306P_Vertical |  | 1 | single turn
53 | Binary counter 14 stages (asynchronous) | 4020 | U3 | 4020 | DIP-16_W7.62mm_Socket |  | 1
54 | Octal Buffer and Line Driver With 3-State Output, complementary enables, non-inverting outputs | 74LS241 | U14 | 74LS241 | DIP-20_W7.62mm_Socket |  | 1
55 | 20MHz, 2kB Flash, 128B SRAM, 128B EEPROM, debugWIRE, DIP-14 | ATtiny24A-P | U11 | ATtiny24A-P | DIP-14_W7.62mm |  | 1
56 | Positive 100mA 30V Linear Regulator, Fixed Output 5V, TO-92 | L78L05_TO92 | U8 | L78L05_TO92 | TO-92_Inline_Wide |  | 1
57 | Dual Operational Transconductance Amplifiers with Linearizing Diodes and Buffers, DIP-16/SOIC-16 | LM13700 | U12 U13 | LM13700 | DIP-16_W7.62mm_Socket |  | 2
58 | Echo Processor IC | PT2399 | U6 | PT2399 | DIP-16_W7.62mm_Socket |  | 1
59 | Dual Low-Noise JFET-Input Operational Amplifiers, DIP-8/SOIC-8 | TL072 | U2 U4 U9 U15 | TL072 | DIP-8_W7.62mm_Socket |  | 4
60 | Quad Low-Noise JFET-Input Operational Amplifiers, DIP-14/SOIC-14 | TL074 | U1 U5 U7 U10 U16 | TL074 | DIP-14_W7.62mm_Socket |  | 5

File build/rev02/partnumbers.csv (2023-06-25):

parttype | value | spec | quantity | info | order code | part number | mouser | farnell | other
diode | 1n5818 |  | 4 |  |  | 1n5818 | 833-1N5818-TP
diode | 1n4148 |  | 16 |  |  | 1n4148 | 512-1N4148
diode | 6v8 | 6.8v zener | 2 |  |  | bzx79-c6v8,133 | 771-BZX79-C6V8133
capacitor | 22pf | ceramic c0g | 16 |  |  | fg28c0g1h220jnt06 | 810-FG28C0G1H220JNT0
capacitor | 220pf | ceramic c0g | 3 |  |  | fg28c0g1h221jnt06 | 810-FG28C0G1H221JNT6
capacitor | 220pf | film polypropylene | 2 |  |  | fkp2d002201d00jssd | 505-FKP2220/100/5
capacitor | 560pf | ceramic c0g | 2 |  |  | fg28c0g1h561jnt06 | 810-FG28C0G1H561JNT0
capacitor | 4n7f | ceramic c0g | 2 |  |  | fg28c0g1h472jnt06 | 810-FG28C0G1H472JNT6
capacitor | 10nf | ceramic c0g | 3 |  |  | fg28c0g1h103jnt06 | 810-FG28C0G1H103JNT0
capacitor | 100nf | ceramic x7r | 27 |  |  | k104k15x7rf53h5 | 594-K104K15X7RF53H5
capacitor | 100nf | ceramic c0g | 4 |  |  | fg26c0g1h104jnt06 | 810-FG26C0G1H104JNT0
capacitor | 470nf | ceramic x7r | 1 |  |  | k474k20x7rf53h5 | 594-K474K20X7RF53H5
capacitor | 10uf | electrolytic | 3 |  |  | uvr1h100mdd | 647-UVR1H100MDD
capacitor | 10uf | electrolytic audio | 2 |  |  | ufw1h100mdd | 647-UFW1H100MDD
capacitor | 47uf | electrolytic | 1 |  |  | uvr1h470med | 647-UVR1H470MED
resistor | 330r | metal film | 18 |  |  | mfr50sfte52-330r | 603-MFR50SFTE52-330R
resistor | 220r | metal film | 8 |  |  | mfr50sfte52-220r | 603-MFR50SFTE52-220R
resistor | 470r | metal film | 2 |  |  | mfr-50sfrf52470r | 603-MFR-50SFRF52470R
resistor | 22r | metal film | 1 |  |  | mfr50sfte52-22r | 603-MFR50SFTE52-22R
resistor | 1k | metal film | 4 |  |  | mfr50sfte52-1k | 603-MFR50SFTE52-1K
resistor | 2k2 | metal film | 4 |  |  | mfr50sfte52-2k2 | 603-MFR50SFTE52-2K2
resistor | 4k7 | metal film | 1 |  |  | mfr50sfte52-4k7 | 603-MFR50SFTE52-4K7
resistor | 6k8 | metal film | 1 |  |  | mfr50sfte52-6k8 | 603-MFR50SFTE52-6K8
resistor | 10k | metal film | 13 |  |  | mfr50sfte52-10k | 603-MFR50SFTE52-10K
resistor | 20k | metal film | 7 |  |  | mfr50sfte52-20k | 603-MFR50SFTE52-20K
resistor | 22k | metal film | 5 |  |  | mfr50sfte52-22k | 603-MFR50SFTE52-22K
resistor | 33k | metal film | 2 |  |  | mfr50sfte52-33k | 603-MFR50SFTE52-33K
resistor | 47k | metal film | 7 |  |  | mfr50sfte52-47k | 603-MFR50SFTE52-47K
resistor | 51k | metal film | 1 |  |  | mfr50sfte52-47k | 603-MFR50SFTE52-51K
resistor | 100k | metal film | 47 |  |  | mfr50sfte52-100k | 603-MFR50SFTE52-100K
resistor | 120k | metal film | 2 |  |  | mfr50sfte52-120k | 603-MFR50SFTE52-120K
resistor | 180k | metal film | 3 |  |  | mfr50sfte52-180k | 603-MFR50SFTE52-180K
resistor | 220k | metal film | 4 |  |  | mfr50sfte52-220k | 603-MFR50SFTE52-220K
resistor | 330k | metal film | 3 |  |  | mfr50sfte52-330k | 603-MFR50SFTE52-330K
resistor | 560k | metal film | 3 |  |  | mfr50sfte52-560k | 603-MFR50SFTE52-560K
resistor | 1m5 | metal film | 1 |  |  | mfr50sfte52-1m5 | 603-MFR50SFTE52-1M5
transistor | 2n3904 |  | 6 |  |  | 2n3904 | 512-2N3904BU
transistor | bc549c |  | 1 |  |  | no part number
transistor | 2n3906 |  | 3 |  |  | 2n3906 | 512-2N3906BU
transistor | bc547 |  | 1 |  |  | no part number
regulator | l78l05_to92 |  | 1 |  |  | L78L05ACZ | 511-L78L05ACZ
ic | lm13700 |  | 2 |  |  | LM13700N/NOPB |  |  | thonk
ic | pt2399 |  | 1 |  |  | pt2399 |  |  | bitsbox
ic | tl072 |  | 4 |  |  | TL072IP | 595-TL072IP
ic | tl074 |  | 5 |  |  | TL074CN | 595-TL074CN
ic | cd4020 |  | 1 |  |  | CD4020BE | 595-CD4020BE
ic | 74ls241 |  | 1 |  |  | SN74LS241N | 595-SN74LS241N
ic | attiny24a-p |  | 1 |  |  | ATTINY24A-PU | 556-ATTINY24A-PU
potentiometer | 100kb |  | 20 |  |  | RV16AF-10-17K-B100K |  |  | thonk
socket | eurorack mono jack |  | 26 |  |  | wqp-pj398sm |  |  | thonk
trimmer | 100r | single turn | 1 |  |  | 3306P-1-101 | 652-3306P-1-101
trimmer | 200k | single turn | 1 |  |  | 3306P-1-204 | 652-3306P-1-204
connector | conn_01x04_female |  | 4 |  |  | no part number |  |  | thonk
connector | conn_01x04_male |  | 4 |  |  | no part number |  |  | thonk
connector | conn_01x03_male |  | 2 |  |  | no part number |  |  | thonk
connector | conn_01x06_female |  | 2 |  |  | no part number |  |  | thonk
connector | conn_01x06_male |  | 2 |  |  | no part number |  |  | thonk
connector | conn_01x08_female |  | 2 |  |  | no part number |  |  | thonk
connector | conn_01x08_male |  | 2 |  |  | no part number |  |  | thonk
connector | conn_02x04_odd_even |  | 1 |  |  | no part number |  |  | thonk
connector | conn_02x03_male |  | 1 |  |  | no part number |  |  | thonk
connector | eurorack power small |  | 1 |  |  | 61201021621 | 710-61201021621 |  | thonk

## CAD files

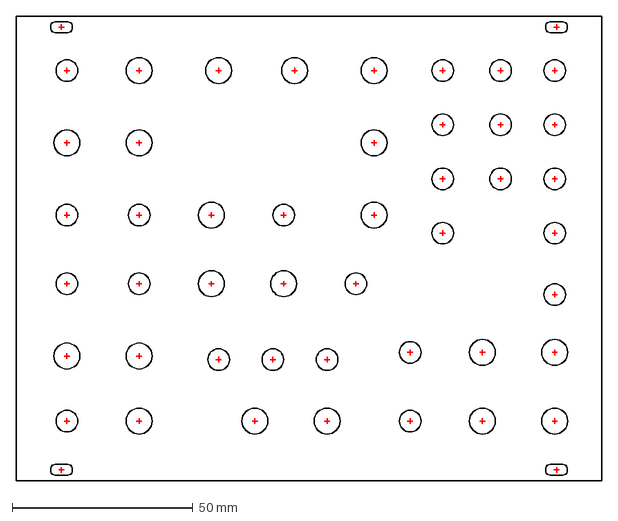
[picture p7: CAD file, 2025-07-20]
panel/ouroboros-front-panel.dxf
162.0 x 128.5 mm

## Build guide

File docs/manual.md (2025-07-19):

# Ouroboros

Ouroboros is an instrument built for playing with feedback systems.

At it's core, it's a resonant filter, a delay, a comparator and pulse dividers arranged in a loop so that the sounds it generates create the signals it uses to modulate itself.

The default routing allows it to shift between locked, rhythmic melodies, and howling walls of noise, but with plenty of space in between to explore.

## Getting started

If you just want to start using Ouroboros and aren't yet interested in how it fits together, then the following should give you a place to start.

Audio output is the jack on the very bottom left of the panel.

Set the following controls to 12 o'clock
* All attenuverters
* Dry and Wet output controls
* Delay Time and Input
* Stability and Rate
* Frequency
* Noise mix input

Set the following controls to the minimum
* Wet and Clock mix input
* VCA Level
* Feedback

Set the resonance to not quite the maximum.

You should now have sound being created.

Play with the Stability and Rate controls to get things moving at the speed you want.

## How it works

Whilst ultimately it's the combination of all of the parts interacting that makes things interesting, it's helpful to understand each of them separately to get an idea of what everything is doing.

### Filter

The filter is a fairly standard state-variable, 12db per-octave design built around the 2164 gain cell chip. The cut-off frequency and resonance are voltage controllable with attenuverters on both.

There's also a dedicated ping input which is the primary sound generator when nothing else is patched.

The band pass output of this is what feeds the delay, whilst the low-pass and high-pass outputs, as well as volt-per-octave control and a direct input are available via the expansion module that connects to a header on the back.

### Delay

The delay is built around the well known PT2399 IC which gives a good range of times, gradually disintegrating into clicks and noise as they get longer. Delay times are voltage controllable with an attenuverter.

On the input, as the control increases past 12 o'clock, soft-clipping distortion will be added to the signal. The output has separate Wet and Dry controls which feed the final mix, as well as a feedback control which will let the whole thing self oscillate, and add in soft-clipping distortion as well.

One interesting thing to node, is that as well as a Wet output jack, there is also a Clock output, which gives the 0-5 volt square wave oscillator that is derived from the digital clock in the chip. The frequency of this will change along with the delay time.

### VCA

The VCA is a simple, linear VCA that is normalled to take the Dry/Wet mix output from the delay and feed it back to the input of the filter. The level CV has an attenuverter and it's DC-coupled so can be used to modulate CV itself.

### Mixer and Comparator

The delay Wet and Clock signals are combined with a Noise source with the mixed signal being fed into a comparator. This is used to generate squared pulses from any signal fed into it. The Stability control is used to set the threshold for the comparator and helps to give some control over how much it will trigger.

### Clock Divider

The signal output from the Comparator is sent to a variable divider which can divide by any value from 1 to 128. This slower signal then feeds further clock dividers which divide by 2, 3, 4, 5, 6, 7 and 8.

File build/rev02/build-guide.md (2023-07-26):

# Ouroboros Build Docs - Revision 2

The Ouroboros is a fairly big build, with a lot of parts, but it shouldn't be an especially difficult one as long as you don't try to rush things.
Mostly it's just a case of putting the parts in the right places and soldering them in, but because this is an early-ish prototype there's a couple of minor issues that need to be fixed. This guide will cover them, with pictures, and try to be as clear as possible with how to go about putting the module together to make sure it all works out fine.

## Building

When building any electronics, it's important to remember that the neater and more methodical you are with placing and soldering the parts, the more likely you are to have a working circuit without a bunch of debugging. There are a few parts placements in the ouroboros that are a little non-standard but for the most part everything should be as expected.

The best way to make sure things go well is to use the interactive bom webpage that's available as part of this project. You can use it to highlight where specific parts go and tick them off once they're placed. It makes life much easier and much less error prone.

### Basics

If you've built some modules before then most of what's here should be obvious, but if not then hopefully you'll find some of the information here useful. It's worth reading it all as this covers instructions for some specific parts.

* Make sure the parts that are meant to lie flat against the board are well set and pressed snugly against the PCB.
* Double check your solder joints. If you're not sure what a good or bad joint looks like then [this guide from adafruit](https://learn.adafruit.com/adafruit-guide-excellent-soldering/common-problems) has some really useful images.
* Trim the legs of soldered devices neatly.
* Certain parts are polarized and have a specific way they should be soldered into the circuit. This should be shown by the footprint on the PCB.
* With parts that need to have their legs bent to be placed in the board, it's easiest to do this before placing them in the PCB.

### Different Parts

##### Resistors

Resistors don't have a direction they need to be solder in, but they should be seated and aligned well. There are a few resistors in the ouroboros that need to go in vertically, and for these just carefully bend one of the legs through 180 degrees and then place them.
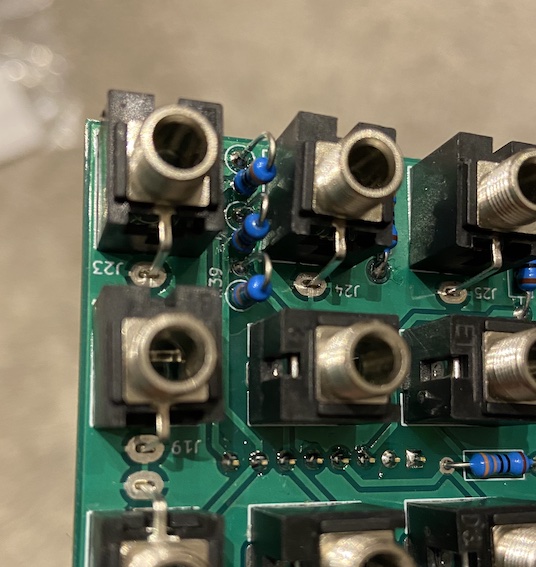
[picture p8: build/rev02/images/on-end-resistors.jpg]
On end resistors


##### Diodes

Diodes have to go in with a specific orientation and the circuits won't work properly if they're wrong. There should be a line at one end of the part itself, and a line in the rectangle of the footprint symbol. Make sure these are both at the same end once the part is placed.

##### Capacitors

There are quite a few different types of capacitors used in the circuit, and even though some of them have the same values, they need to go in the correct places. The long, cylindrical capacitors are electrolytic and need to go in the correct orientation. Usually they would also be upright, but in this build they need to have their legs bent at a 90 degree angle and be placed lying down.
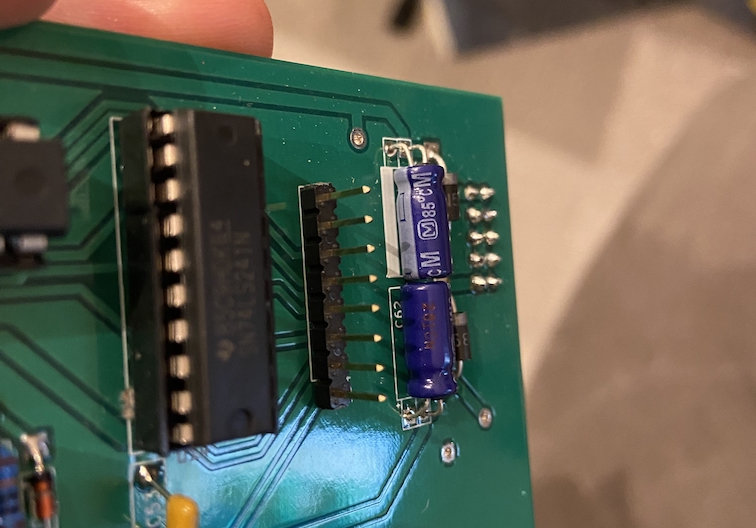
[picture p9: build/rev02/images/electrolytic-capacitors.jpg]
Electrolytic capacitors


There are two other places that confusion with the capacitor values may happen. One is with the 100nF capacitors, where there are both X7R and C0G capacitors. The second is with the 220pF capacitors where there are C0G and film types. The interactive bom webpage does specify the type of caps that need to go in each place, but it's really worth double checking what should be placed.

The X7R and C0G caps should all have the type written on their labels. The film caps don't have labels, but they're bright red and quite chunky so shouldn't be hard to miss. They may also be a little bit awkward to place because I didn't give them quite enough space on the board. Check the fixes for more information.

##### Transistors

The transistors in the circuit should be placed so their flat and curved sides match the footprint on the PCB. Q2 is an exception to this, see the fixes for more information. There are multiple different types of transistor, all of which need to go in the correct places. The bom webpage should show them. There's also the L78L05 voltage regulator, that looks like a transistor but isn't. Don't get it confused with them.

##### IC Sockets

All the ICs in the circuit should use sockets as this makes debugging and error finding much easier. The sockets themselves will work in either orientation, but it's generally a good idea to make sure the notched end of the socket matches the PCB footprint so it's easier to make sure you put the chips in the correct way round.

### Build Order

Different people likely have their preferred ways to build things, and if you're used to something different then feel free to disregard this. Generally the easiest way to go about building is to start with the lowest height components first and work up. My preferred ordering would be

* diodes
* resistors
* IC sockets
* capacitors
* transistors
* trimmers
* pin headers and sockets
* jacks and potentiometers

Some people find it easier to place the capacitors before IC sockets, but my experience is that the caps are taller and it's more faff. Also with this revision there's an issue with spacing for two of the caps, so the socket for U10 really needs to be placed first.

### Pin Headers and Sockets

TODO this section needs to be written, but basically it's just a bit awkward unfortunately.

### Faceplate, Jacks and Potentiometers

Getting the jacks and potentiometers correctly aligned with the faceplate is important to do correctly. The main thing is to have the front panel on and holding them in place before then soldering them. Ideally the process would be

* Place some or all of the jacks and pots in the PCB but don't solder them in
* Make sure there's enough of them in place that the front panel will be properly supported
* Put the front panel on and screw it on with a few of the nuts
* These only need to be hand tightened as it's just to hold the panel in place
* Carefully flip the pcb and panel together and solder the pots and jacks in
* If you only did some of them then remove the front panel, place the rest, put the front panel back on and solder everything in

This should mean that everything is held in place and correctly aligned.

## Fixes and bugs

There are two fixes required for the rev2 PCBs. One that requires cutting a trace then bridging two pins with solder, and the second that's just a transistor that needs to be placed with a different orientation from the PCB footprint.

There's also a couple of bugs with this version as well. None of these problems are major but they're worth calling out to prevent confusion. There's one place where the sizing of the parts is a little off, so you need to make sure you place them in a certain order otherwise things may be awkward. There's also a couple of the headers on the back that aren't used because they're unnecessary or wrong.

#### U14

On IC U14, pin 19 needs to have the connections between it and the ground plane cut carefully and then a connection made between it and pin 20. If you got the boards from me then the cutting should already have been done. The bridging can be done after the IC socket has been soldered in and can simply be blobbed solder between the pins.

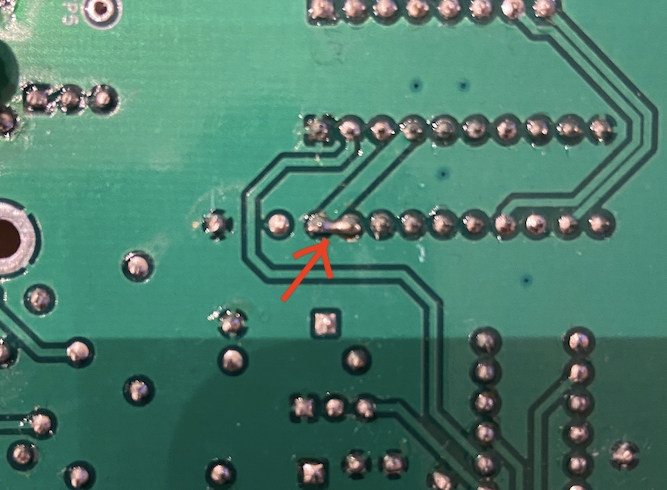
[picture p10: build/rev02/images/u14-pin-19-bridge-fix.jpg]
U14 fix


#### Q2

Q2 is on the front panel board that holds all the jacks and controls. Assuming that you have the BC547C transistor from the kit, you'll need to place this in the reverse orientation from the footprint on the PCB.

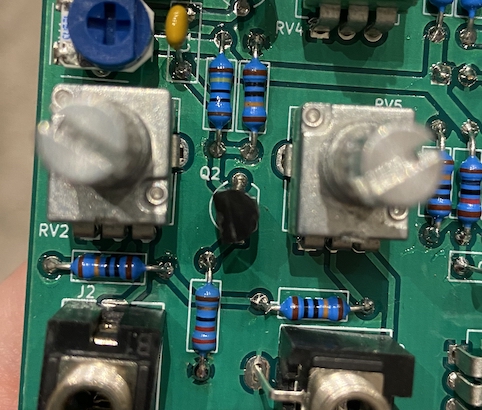
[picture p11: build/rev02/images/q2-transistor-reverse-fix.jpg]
Q2 fix


#### C48 and C49

There hasn't quite been enough space given for these capacitors to fit next to the IC socket, and whilst they can still be placed, they may not sit quite properly. This won't affect the way they work at all. The important thing is to make sure you place the IC socket before placing the caps. Otherwise you may have to carefully desolder them to get the socket in.

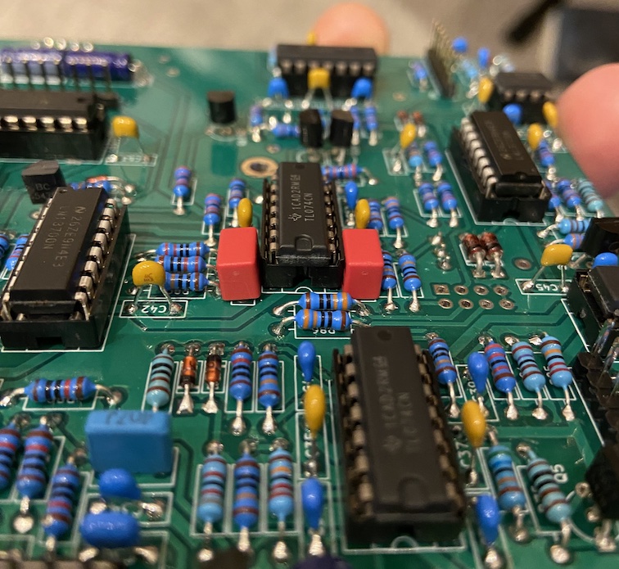
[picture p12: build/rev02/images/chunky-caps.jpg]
Chunky Caps


#### J39

This is meant to be the header to use for programming the ATTiny, but unfortunately the pin connections to the chip are wrong. This won't affect the circuit, and you should have been given a pre-programmed chip as part of the kit, but it means if you want to reprogram it at some point in the future you'll need to remove it from the circuit.

#### JP1

This part is redundant and so you shouldn't place anything here.

#### J38

This header is for more outputs from the filter. I've not yet built anything to use these so you don't need to place any header here.

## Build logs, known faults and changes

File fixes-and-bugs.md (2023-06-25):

# Fixes and Bugs

Fixes and caveats for any versions of the PCB that need them.

## Revision 2

Pin 19 on IC U14 is incorrectly connected to ground.
Using a sharp blade, cut the ground traces around the pin and then solder a jumper between pins 19 and 20.

The in-circuit programmer header for the ATTiny is connected to the incorrect pins so isn't usable.

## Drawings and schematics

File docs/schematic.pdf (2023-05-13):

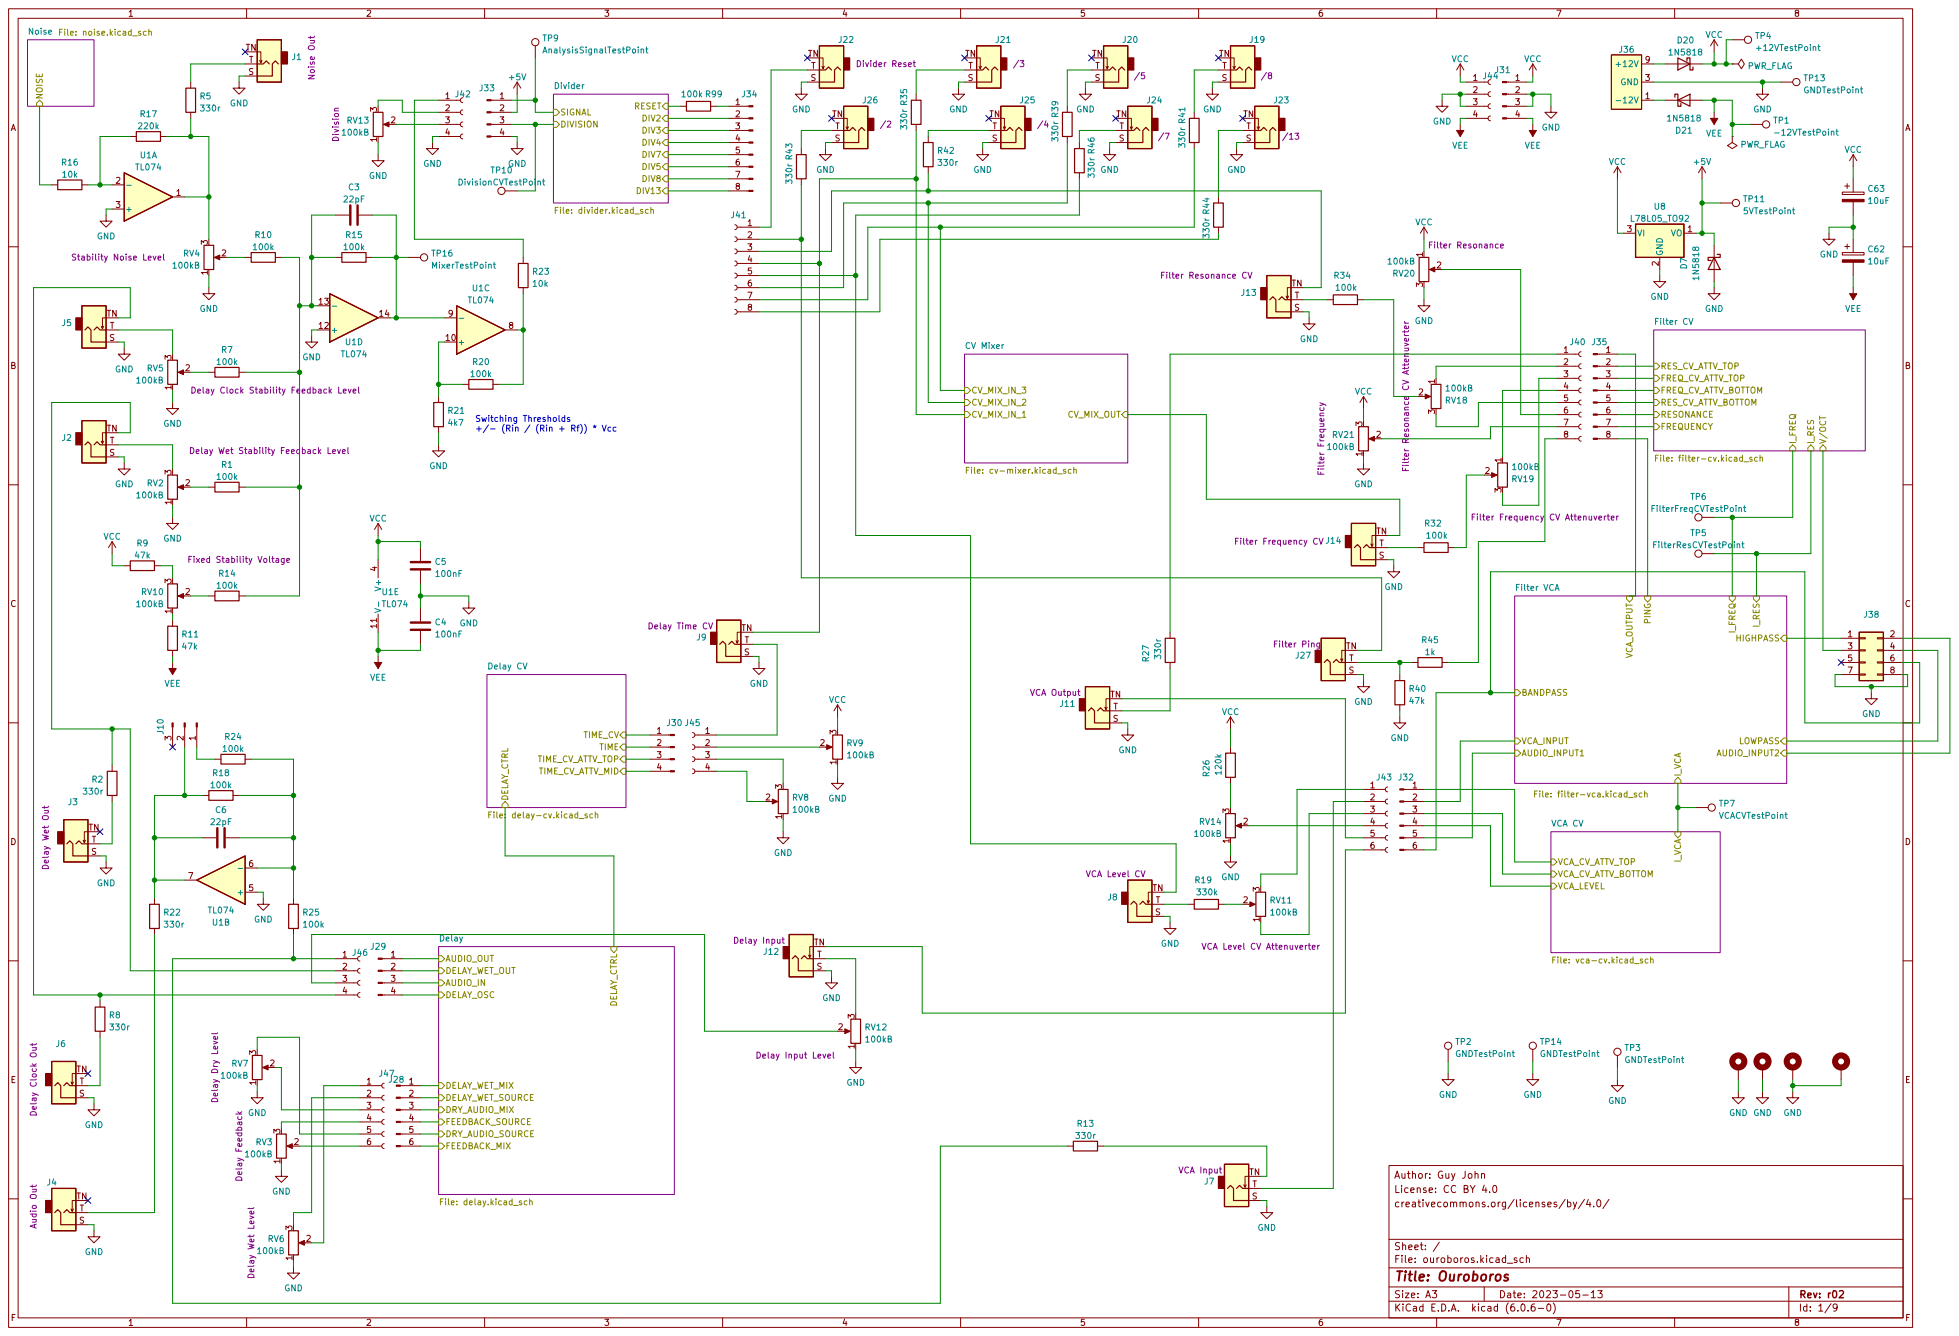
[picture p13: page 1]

CV_MIX_OUT CV_MIX_IN_2 CV_MIX_IN_3 CV_MIX_IN_1 CV Mixer File: cv-mixer.kicad_sch DIVISION

J13 Filter Resonance CV GND

+/- (Rin / (Rin + Rf)) * Vcc

File: filter-cv.kicad_sch PING

File: ouroboros.kicad_sch Sheet: / creativecommons.org/licenses/by/4.0/ License: CC BY 4.0 Author: Guy John DELAY_OSC

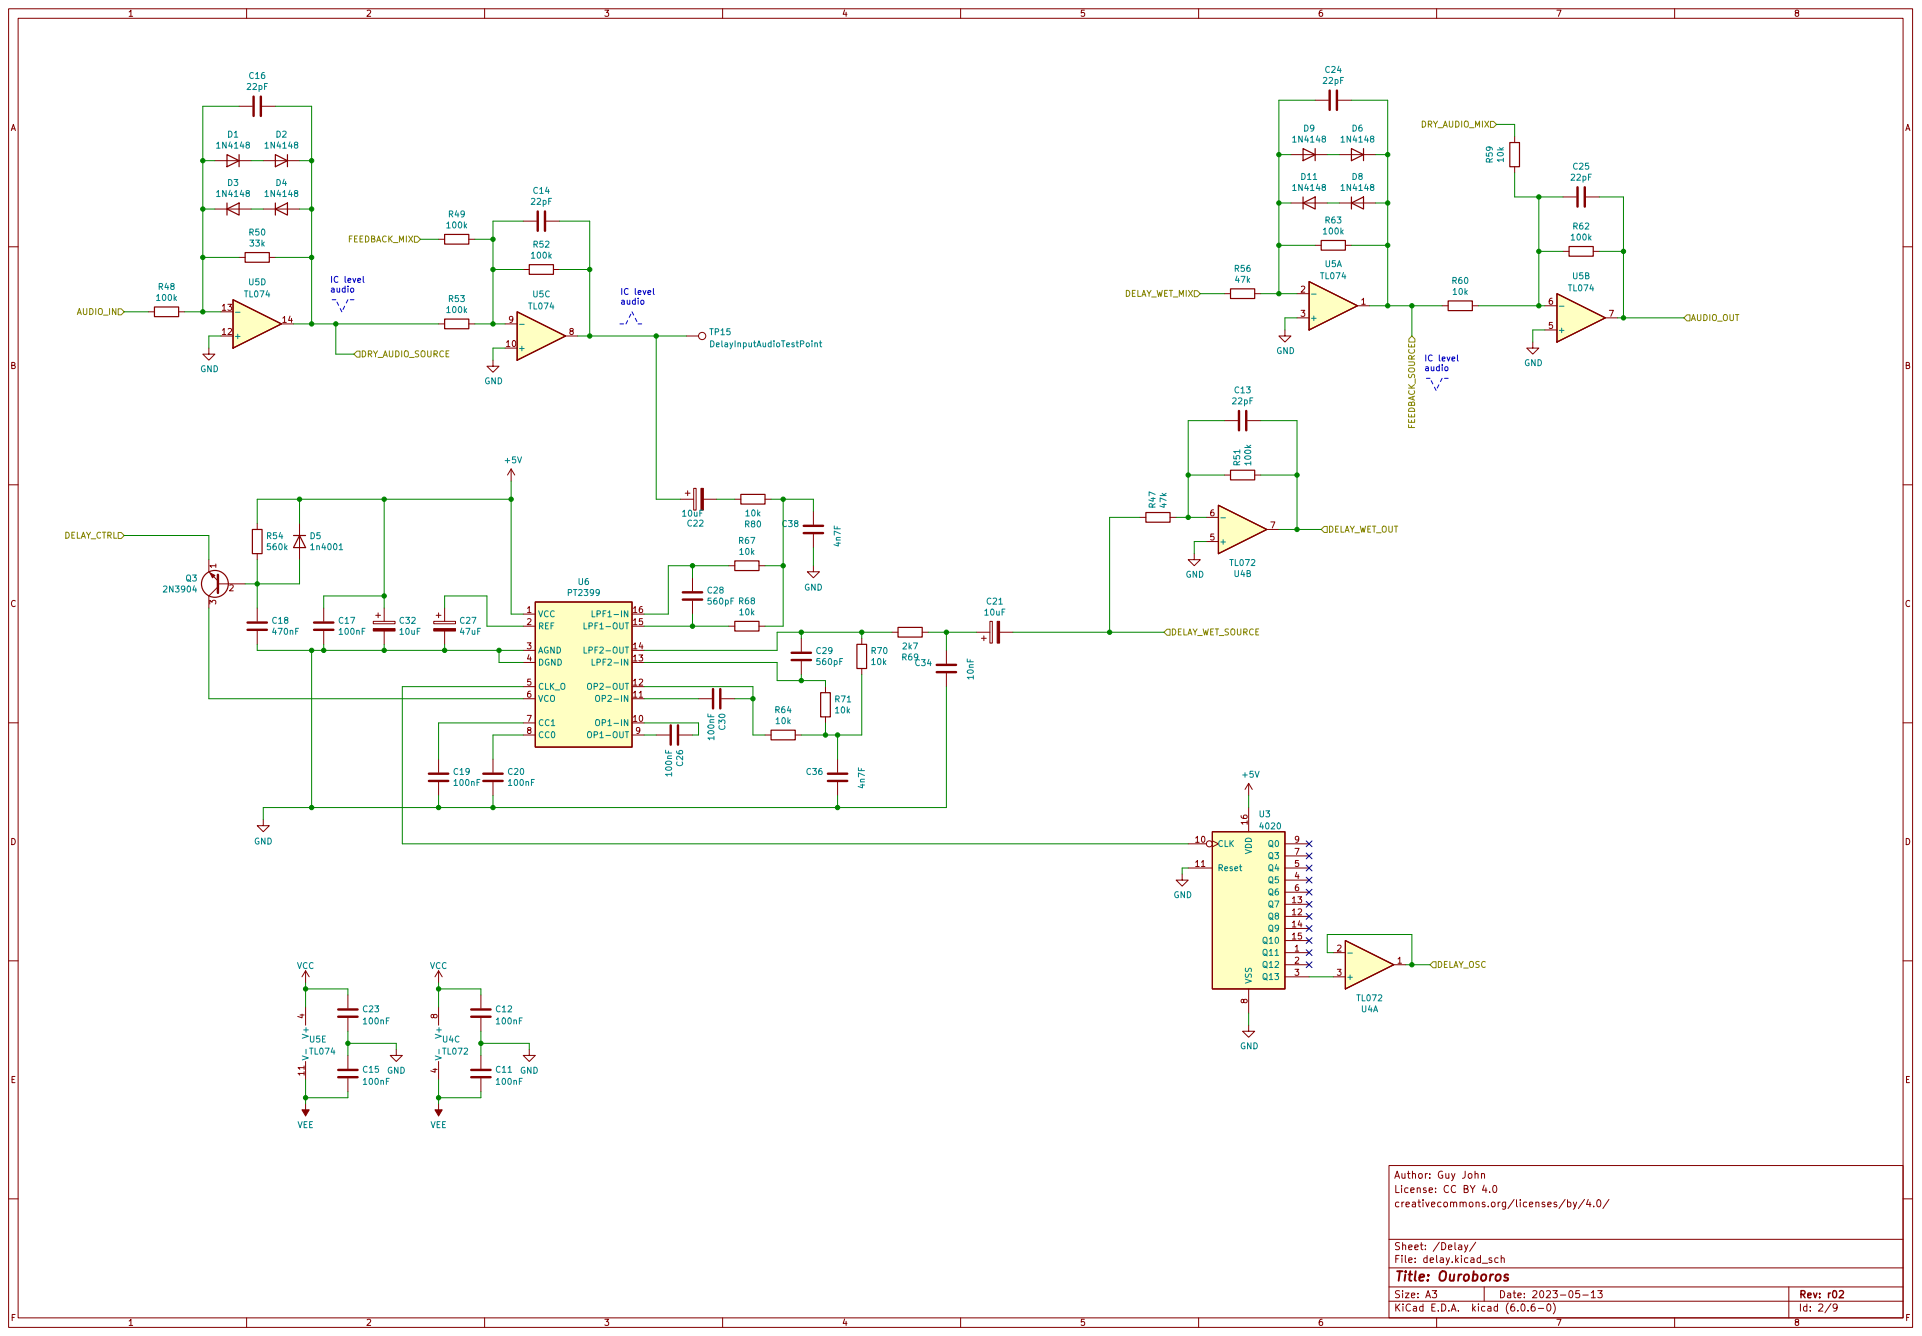
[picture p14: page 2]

creativecommons.org/licenses/by/4.0/ License: CC BY 4.0 Author: Guy John

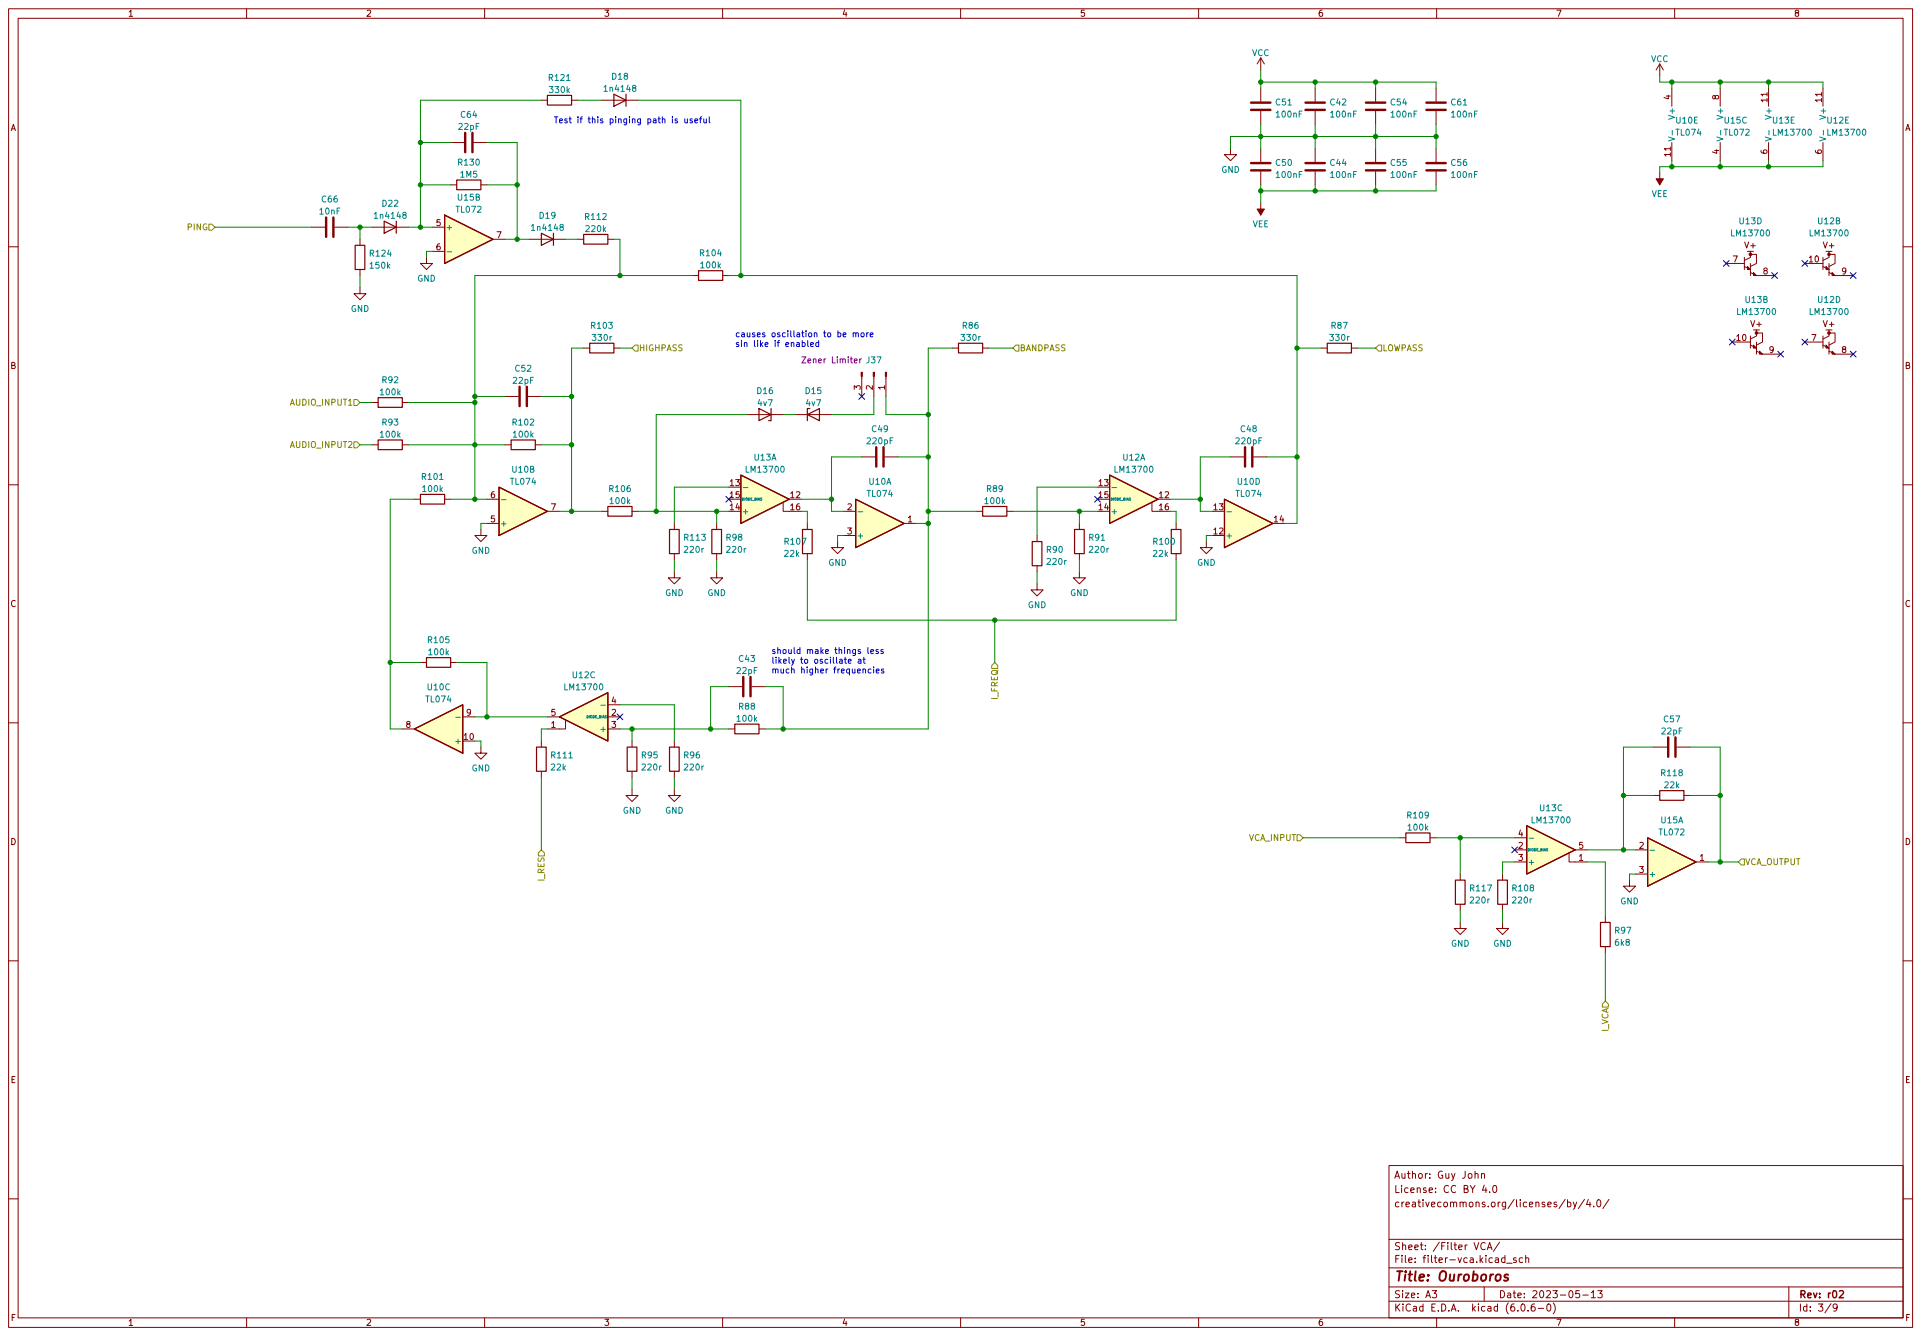
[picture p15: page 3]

Test if this pinging path is useful

causes oscillation to be more
sin like if enabled

should make things less
likely to oscillate at
much higher frequencies

File: filter-vca.kicad_sch Sheet: /Filter VCA/ creativecommons.org/licenses/by/4.0/ License: CC BY 4.0 Author: Guy John

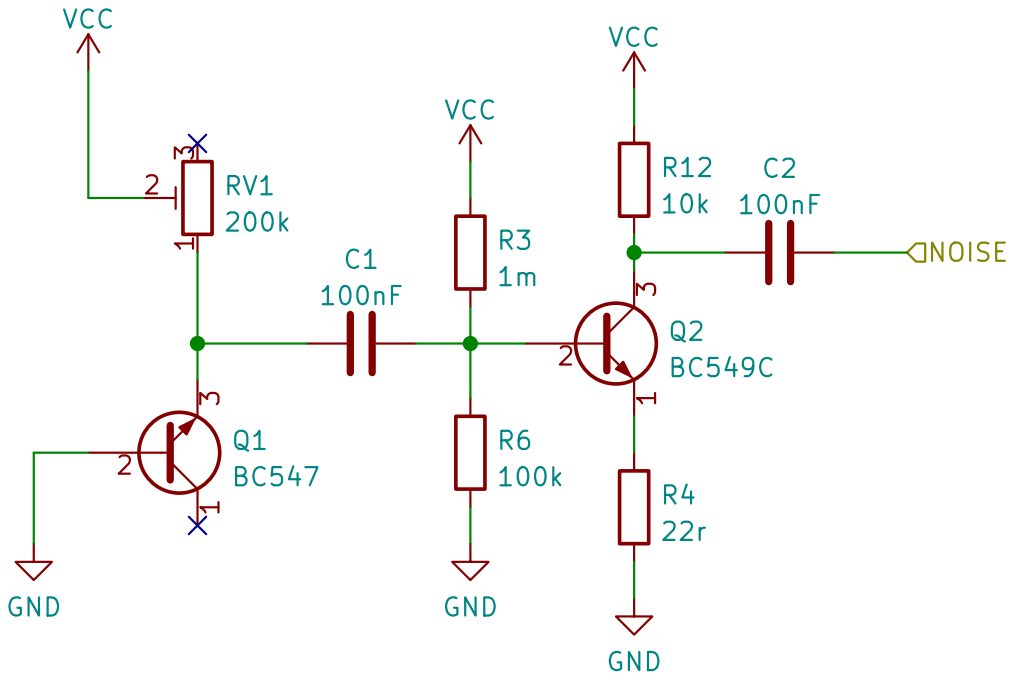
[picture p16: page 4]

File: noise.kicad_sch Sheet: /Noise/ creativecommons.org/licenses/by/4.0/ License: CC BY 4.0 Author: Guy John R4
22r GND

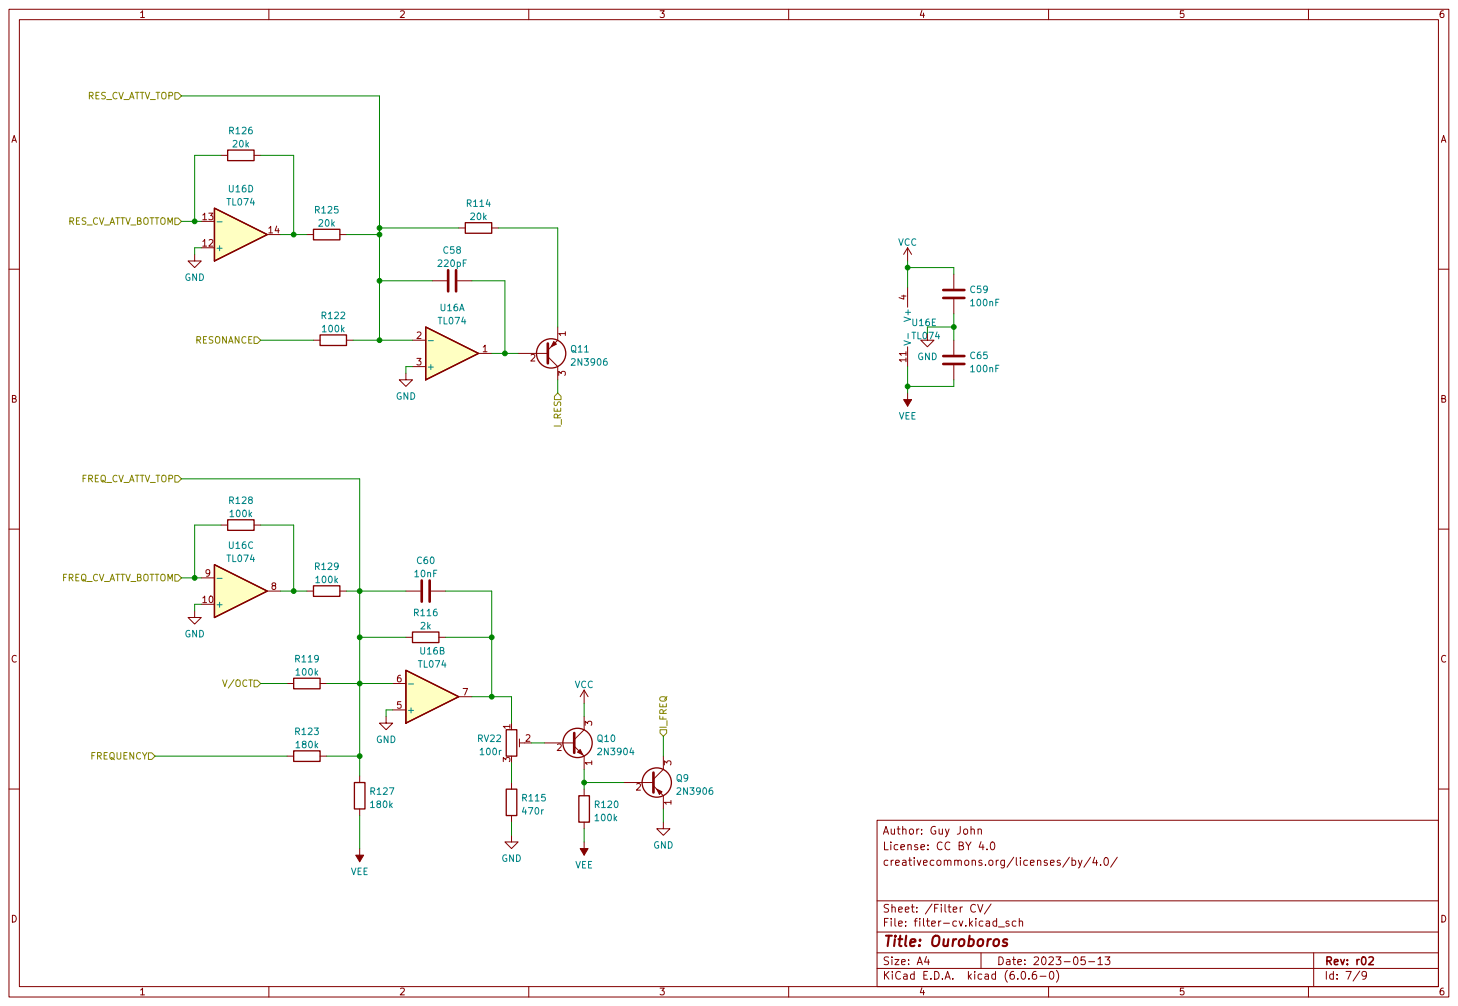
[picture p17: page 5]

File: filter-cv.kicad_sch Sheet: /Filter CV/ creativecommons.org/licenses/by/4.0/ License: CC BY 4.0 Author: Guy John

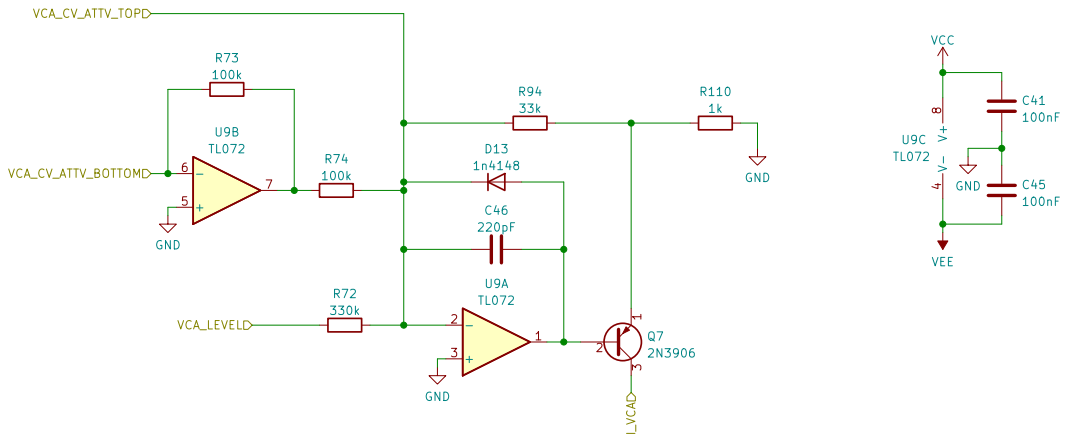
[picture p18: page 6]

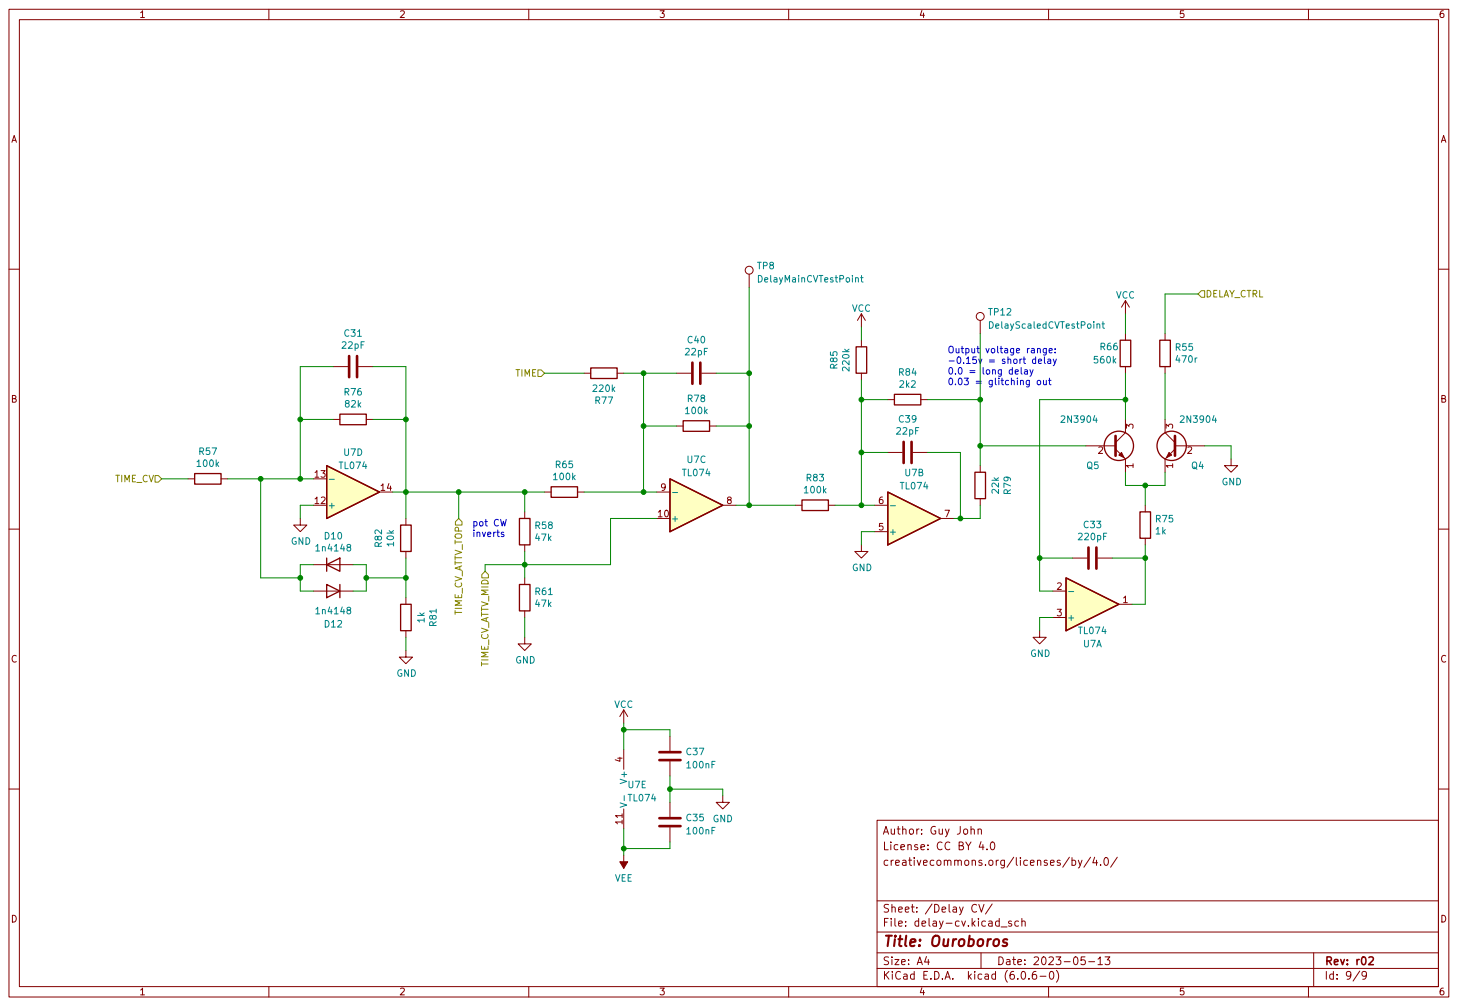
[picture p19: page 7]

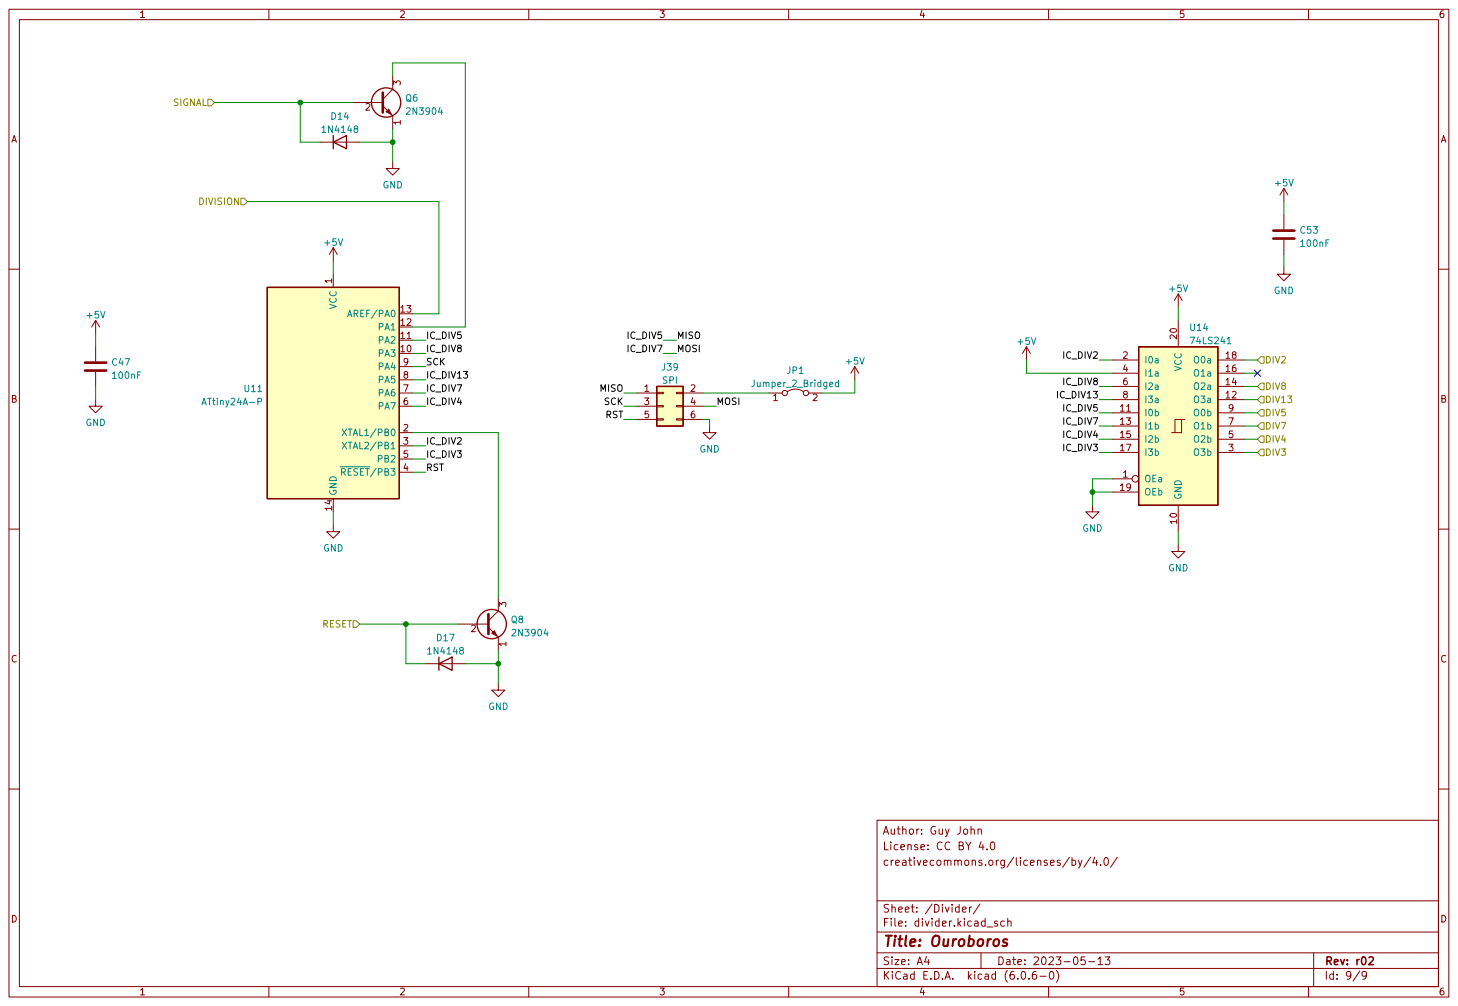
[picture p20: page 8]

File: divider.kicad_sch Sheet: /Divider/ creativecommons.org/licenses/by/4.0/ License: CC BY 4.0 Author: Guy John

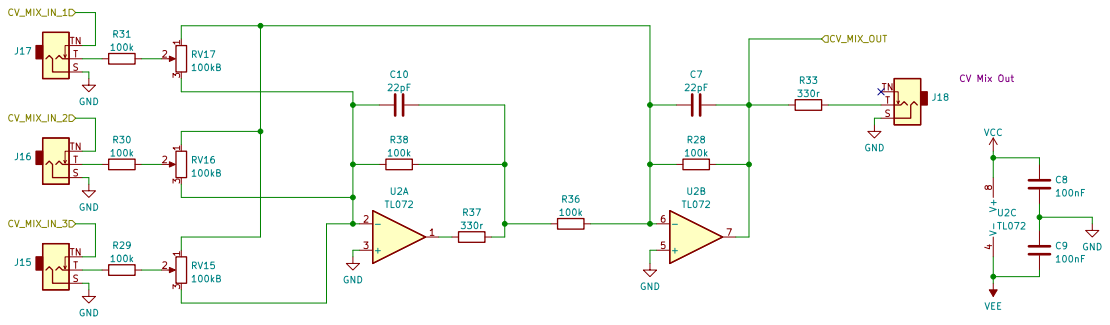
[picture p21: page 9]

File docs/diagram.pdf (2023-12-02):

## Ouroboros

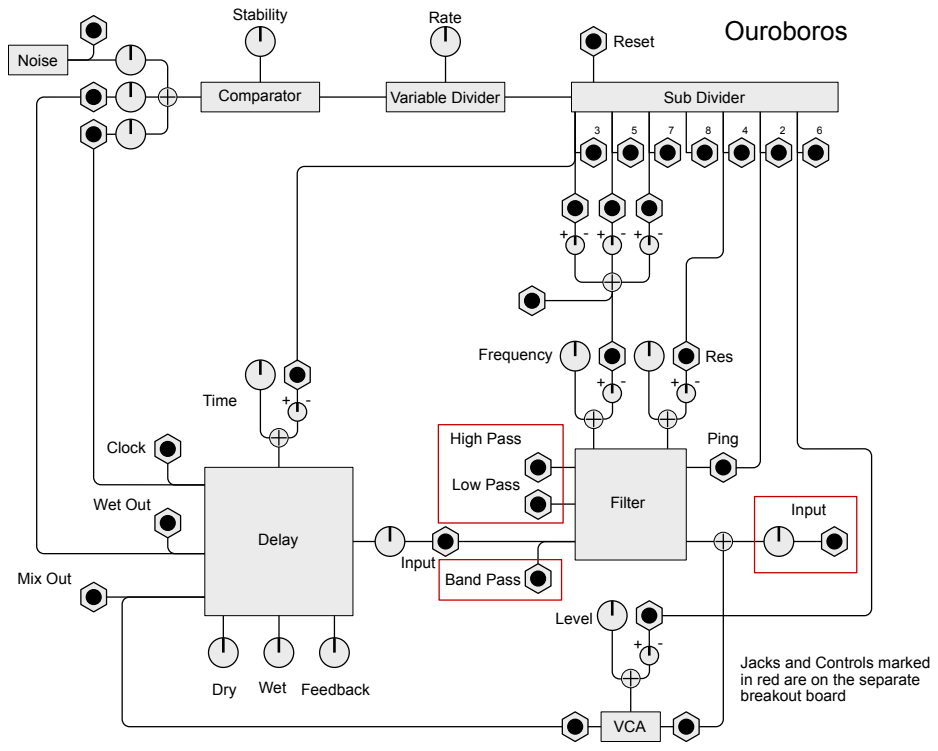
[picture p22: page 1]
Frequency; VCA; Input; Ping; Filter; Low Pass; Band Pass; High Pass; Level; Comparator; Stability; Rate; Variable Divider; Sub Divider; Reset; Dry; Wet Feedback; Mix Out; Wet Out; Time; Delay; Clock; Noise; Res

Jacks and Controls marked
in red are on the separate
breakout board

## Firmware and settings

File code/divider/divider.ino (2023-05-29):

#define DIV_CV_PIN A0

#define SIG_IN_PIN 1 // PA1
#define RESET_PIN 10 // PB0

#define MIN_PULSE_DIVIDE 1
#define MAX_PULSE_DIVIDE 64
float DIVIDE_DELTA = float(MAX_PULSE_DIVIDE - MIN_PULSE_DIVIDE);

int mainPulseCount = 0;
int mainPulseLimit = 1;

#define OUTPUT_COUNT 7
// PB1, PA7, PB2, PA2, PA6, PA3, PA5
int divOutputPins[OUTPUT_COUNT] = {9, 7, 8, 2, 6, 3, 5};
int divCounts[OUTPUT_COUNT] = {0, 0, 0, 0, 0, 0, 0};
int divLimits[OUTPUT_COUNT] = {2, 3, 4, 5, 6, 7, 8};


int pulseCheck = 1;
int resetCheck = 1;


void setup()
{
  for (int i = 0; i < OUTPUT_COUNT; i++) {
    pinMode(divOutputPins[i], OUTPUT);
  }

  pinMode(SIG_IN_PIN, INPUT_PULLUP);
  pinMode(RESET_PIN, INPUT_PULLUP);
}

void loop()
{
  checkDivisionCount();
  checkPulse();
  checkReset();
}

void checkDivisionCount() {
  float divCV = float(analogRead(DIV_CV_PIN)) / 1023.0;
  mainPulseLimit = MIN_PULSE_DIVIDE + int(DIVIDE_DELTA * divCV);
}

void checkReset() {
  int resetInput = digitalRead(RESET_PIN);
  if (resetInput == LOW) {
    resetCheck = 0;
  } else if (resetCheck == 0 && resetInput == HIGH) {
    resetCheck = 1;
    for (int i = 0; i < OUTPUT_COUNT; i++) {
    clearSubCount(i);
    }
  }
}

void checkPulse() {
  int pulseInput = digitalRead(SIG_IN_PIN);
  if (pulseInput == LOW) {
    pulseCheck = 0;
  } else if (pulseCheck == 0 && pulseInput == HIGH) {
    pulseCheck = 1;
    incrementMainCount();
  }
}

void incrementMainCount() {
  mainPulseCount += 1;
  if (mainPulseCount < mainPulseLimit) { return; }
  mainPulseCount = 0;

  for (int i = 0; i < OUTPUT_COUNT; i++) {
   incrementSubCount(i);
  }
}

void incrementSubCount(int idx) {
  divCounts[idx] += 1;
  if (divCounts[idx] >= divLimits[idx]) {
    divCounts[idx] = 0;
    digitalWrite(divOutputPins[idx], HIGH);
  } else {
    digitalWrite(divOutputPins[idx], LOW);
  }
}

void clearSubCount(int idx) {
  divCounts[idx] = 0;
  digitalWrite(divOutputPins[idx], LOW);
}

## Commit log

2022-10-10 component positioning mostly done
    [cv-mixer.kicad_sch, delay-cv.kicad_sch, delay.kicad_sch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]
2022-10-13 initial layout done
    [delay.kicad_sch, filter-cv.kicad_sch, main-divider.kicad_sch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]
2022-10-25 Final changes for rev01
    [cv-mixer.kicad_sch, filter-cv.kicad_sch, filter-vca.kicad_sch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]
2023-04-30 Updating filter analysis docs
2023-04-30 Adding docs to keep track of fixes and changes for rev1
2023-04-30 Full rejig to use attiny for divider
    [cv-mixer.kicad_sch, delay-cv.kicad_sch, delay.kicad_sch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]
2023-04-30 Unsure what these changes to gerbers are...
    [strata-B_Cu.gbl, strata-B_Mask.gbs, strata-B_Silkscreen.gbo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]
2023-04-30 Finished most recent redesign
    probably still needs fixing though
    [delay.kicad_sch, divider.kicad_sch, strata.kicad_sch]
2023-05-01 Layout seems to be all done, though needs further checking
    [delay-cv.kicad_sch, delay.kicad_sch, divider.kicad_sch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]
2023-05-13 Updating layout again
    [divider.kicad_sch, strata.kicad_sch]
2023-05-13 Tweaking VCA circuit
    [strata.kicad_sch, vca-cv.kicad_sch]
2023-05-13 Adding info about current and power
2023-05-13 Changing name to the mercurial machine
    [cv-mixer.kicad_sch, delay-cv.kicad_sch, delay.kicad_sch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]
2023-05-13 Updating name in filter analysis
2023-05-13 Updating name in panel files
    [mercurial-panel-holes.dxf]
2023-05-13 geographically reannotate parts
    [cv-mixer.kicad_sch, delay-cv.kicad_sch, delay.kicad_sch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]
2023-05-13 Updating boms
    [mercurial_bom.csv]
2023-05-13 Changing name again
    [cv-mixer.kicad_sch, delay-cv.kicad_sch, delay.kicad_sch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]
2023-05-13 Adding quote to the pcb
2023-05-13 Updating bom and creating part numbers list
    [filter-vca.kicad_sch, ouroboros.kicad_sch, ouroboros_bom.csv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]
2023-05-13 replotting gerbers
    [ouroboros-B_Cu.gbl, ouroboros-B_Mask.gbs, ouroboros-B_Silkscreen.gbo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]
2023-05-13 creating schematic pdf
2023-05-13 remaking front panel gerbers
    [ouroboros-frontpanel-B_Cu.gbl, ouroboros-frontpanel-B_Mask.gbs, ouroboros-frontpanel-B_Silkscreen.gbo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]
2023-05-29 Updating for kicad 7
    [cv-mixer.kicad_sch, delay-cv.kicad_sch, delay.kicad_sch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]
2023-05-29 Fixing issues in the divider circuitry
    [divider.kicad_sch, ouroboros.kicad_sch]
2023-06-25 Minor tweaks to rev2 values
    [delay-cv.kicad_sch, delay.kicad_sch, filter-cv.kicad_sch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]
2023-06-25 Removing test points from BOM
    [delay-cv.kicad_sch, delay.kicad_sch, ouroboros.kicad_sch]
2023-06-25 Updating zener values
    [filter-vca.kicad_sch]
2023-06-25 Updating bom and partnumbers
    [ouroboros_bom.csv, partnumbers.csv]
2023-07-20 Changing decoupling caps to ceramic X7R
    [cv-mixer.kicad_sch, delay-cv.kicad_sch, delay.kicad_sch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]
2023-07-20 Minor tweaks and additional comments
    [filter-vca.kicad_sch, vca-cv.kicad_sch]
2023-07-20 Regenerating bom
    [ouroboros_bom.csv]
2023-07-25 Updating PCB and rebuilding ibom
    [noise.kicad_sch]
2023-09-10 Update site with revision info
    [ouroboros_bom.csv, partnumbers.csv]
2024-09-16 Adding start of analysis for resonance controls
    [logarithmic-resonance-control.kicad_pcb, logarithmic-resonance-control.kicad_sch]
2025-01-10 Updating for new kicad version
    [cv-mixer.kicad_sch, delay-cv.kicad_sch, delay.kicad_sch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]
2025-01-10 Updating board for new footprint libraries
    [cv-mixer.kicad_sch, delay-cv.kicad_sch, delay.kicad_sch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]
2025-01-11 Tweaking filter resonance control circuitry
    [filter-cv.kicad_sch]
2025-01-11 Tweaking noise circuitry
    [noise.kicad_sch]
2025-01-11 Updating pcb after tweaks
    [ouroboros.kicad_sch]
2025-07-19 Updating with rev03 changes
    [cv-mixer.kicad_sch, delay-cv.kicad_sch, delay.kicad_sch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]
2025-07-20 Digital ground for divider and other layout improvements
    [delay-cv.kicad_sch, delay.kicad_sch, ouroboros.kicad_sch]
2025-07-20 Switching some opamps
    [filter-vca.kicad_sch]
2025-07-20 More layout tweaks
    [delay.kicad_sch, filter-vca.kicad_sch, ouroboros.kicad_sch]
2025-07-20 Updating front panel hole files
    [ouroboros-front-panel.dxf, ouroboros-panel-holes.dxf]
